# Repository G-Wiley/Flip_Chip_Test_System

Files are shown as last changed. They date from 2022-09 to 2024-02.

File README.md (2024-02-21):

# Flip_Chip_Test_System
This Flip-Chip Tester System enables verification testing and debugging of most M-series and some G-series Flip Chip modules. The system is comprised of a Tester board and a Tester Controller board. An accessory called the IC Test Jig plugs into the UUT socket of the tester which enables functional testing of digital ICs.



<p>This tester PCB is heavily based on a tester designed by Michael Thompson with PCB by Vince Slyngstad. Refer to the StearnsMTvrs files in this folder: 
https://svn.so-much-stuff.com/svn/trunk/Eagle/projects/Stearns%20Tester/
<p>The original Flip-Chip Tester was designed by Warren Stearns.  A more detailed and complete history of the tester evolution is here: 
<br>https://so-much-stuff.com/pdp8/repair/fc-tester.php
<p>This Flip Chip Tester PCB is an updated version of the StearnsMTvrs PCB. The changes to this board include:
<ul>
<li>Increased ground connections between the Tester Controller header and the GPIO Expander chips, and between the GPIO Expander chips and the UUT connector. This was accomplished by using smaller vias and re-routing traces that divided pieces of the ground plane. There are also many more vias that connect between layers and ground fill areas that connect across ground plane sections that are separated by signal traces. </li>
<li>A separate chip select signal is connected to each GPIO Expander.</li>
<li>Updated the pinout of the Tester Controller header to connect the separate SPI chip selects and VCC between the Tester and the Tester Controller circuit card.</li>
</ul>
<p>The Tester Controller circuit card has an ESP32 CPU to control the tester and microSD adapter card for storing test vector files. A possible future update is to combine the Tester and Tester Controller onto a single circuit board. 
<p>The original Stearns Tester software has been ported so it can be built in the Arduino development environment. Some software modifications were necessary due to use of the integrated SPI controller in the ESP32 to drive the SPI link to the GPIO Expanders and microSD adapter. Some changes were necessary to run this as an Arduino application.

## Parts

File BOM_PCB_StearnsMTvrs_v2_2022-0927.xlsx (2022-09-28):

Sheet: Tester Circuit Card
ID | Quantity | Name | MPN | Designator | Footprint | Digikey part number | Source | Link
1 | 4 | 2x18 header | Amazon Break-Away 0.1 Inch 2 x 20-pin Strip Male Header | AX1, AX2, BX1, BX2 (cut to 2x18) | 2X18 | - | Amazon | https://www.amazon.com/dp/B083DYVWDN
 | 72 |  |  | jumpers for 36-pin headers |  | - | Amazon | https://www.amazon.com/dp/B07FKKHHM7
3 | 5 | MCP23S17SP | MCP23S17-E/SP | IC1, IC2, IC3, IC4, IC5 | DIL28-3 | MCP23S17-E/SP-ND | Digikey | https://www.digikey.com/en/products/detail/microchip-technology/MCP23S17-E-SP/894276
 |  |  |  |  |  |  | Mouser | https://www.mouser.com/ProductDetail/Microchip-Technology-Atmel/MCP23S17-E-SP?qs=usxtMOJb1RyzobAZrBjFZA%3D%3D
 |  |  |  |  |  |  | AliExpress | https://www.aliexpress.com/item/3256804178404243.html
 |  |  | ICM-328-1-GT-HT | Sockets for IC1 - IC5 |  | 2057-ICM-328-1-GT-HT-ND | Digikey | https://www.digikey.com/en/products/detail/adam-tech/ICM-328-1-GT-HT/9832998
8 | 19 | 1X01 | single 0.025" header pin with plastic base can cut from: Amazon Break-Away 0.1 Inch 2 x 20-pin Strip Male Header | PROBE1, PROBE2, PROBE3, PROBE4, GNDPROBE, LOADL3, LOADL1, LOADHI3, LOADHI1, GNDL3, GNDL1, GNDL2, GNDL0, LED0, LED1, LED2, LED3, GND, VPP | 1X01 | - | -
9 | 2 | Red LED | Jameco 200 piece LED Grab Bag | RED1, RED2 | LED5MM | - | Jameco | https://www.jameco.com/z/GB110-JAMECO-200-Piece-LED-Grab-Bag-T1-3-4-5mm-T1-3mm-Assorted-Colors-and-Shapes_18041.html
18 | 2 | Yellow LED | Jameco 200 piece LED Grab Bag | UUT_PWR, YELLOW | LED5MM | - | Jameco | https://www.jameco.com/z/GB110-JAMECO-200-Piece-LED-Grab-Bag-T1-3-4-5mm-T1-3mm-Assorted-Colors-and-Shapes_18041.html
20 | 2 | Green LED | Jameco 200 piece LED Grab Bag | PWR, GREEN | LED5MM | - | Jameco | https://www.jameco.com/z/GB110-JAMECO-200-Piece-LED-Grab-Bag-T1-3-4-5mm-T1-3mm-Assorted-Colors-and-Shapes_18041.html
10 | 5 | 300 ohm | Substituted 390Ω | R2[note 2], R3[note 2], R4[note 2], R5[note 2], R14[note 2] | 0207/10 |  | Digikey | https://www.digikey.com/en/products/detail/stackpole-electronics-inc/CF18JT390R/1741695 | 390Ω
11 | 2 | 180 ohm | DNI | R6, R7 | 0207/10 | - | - | -
19 | 2 | 1K ohm | Substituted 390Ω for R12, DNI R13 | R12[note 2], R13[note 1] | 0207/10 |  | Digikey | https://www.digikey.com/en/products/detail/stackpole-electronics-inc/CF18JT390R/1741695 | 390Ω
12 | 2 | 560 ohm | DNI | R8[note 1], R9[note 1] | 0207/10 | - | - | -
13 | 1 | 2K ohm | DNI | R10[note 1] | 0207/10 | - | - | -
14 | 1 | 5.6K ohm | DNI | R11[note 1] | 0207/10 | - | - | -
7 | 1 | 100K ohm | 100K | R1 | 0207/10 |  | Digikey | https://www.digikey.com/en/products/detail/stackpole-electronics-inc/CF18JT100K/1741564
15 | 1 | MA13-2 | Amazon Break-Away 0.1 Inch 2 x 20-pin Strip Male Header | PC1 (cut to 2x10) | MA13-2 | - | Amazon | https://www.amazon.com/dp/B083DYVWDN
16 | 2 | 1N4001 | 1N4001 | D1, D2 | DO41-10 | 1N4001DICT-ND - Cut Tape (CT) | Digikey | https://www.digikey.com/en/products/detail/diodes-incorporated/1N4001-T/601
17 | 1 | 710X | 7101SYCBE | UUT | 7109MD9V3 | CKN1003-ND | Digikey | https://www.digikey.com/en/products/detail/c-k/7101SYCBE/13637
21 | 1 | 47uF | any value from 47uF to 100uF, 10V or greater, that fits | C1 | E5-8,5 |  | Digikey
22 | 6 | .22uF | C330C224M1R5TA | C2, C3, C4, C5, C6, C7 | C050-025X075 | 399-13966-ND | Digikey | https://www.digikey.com/en/products/detail/kemet/C330C224M1R5TA/6562377
23 | 1 | 1X6MTA | 1-1123723-6 | POWER, header | 1X6MTA | A106606-ND | Digikey | https://www.digikey.com/en/products/detail/te-connectivity-amp-connectors/1-1123723-6/686929
 | 1 |  |  | Power, mating connector |  | 5-1123722-6-SI-ND | Digikey | https://www.digikey.com/en/products/detail/te-connectivity-amp-connectors/5-1123722-6/4730307
 | 3 |  | 1123721-2 | pins for mating connector |  | A100446CT-ND | Digikey | https://www.digikey.com/en/products/detail/te-connectivity-amp-connectors/1123721-2/686921
24 | 1 | dual 2x18 | Omnibus-compatible connector | EDAC | EDAC346-36-2 | - | AliExpress | https://www.aliexpress.com/item/2255801094078491.html
 |  |  |  | Note 1: I chose not to install R8, R9, R10, R13 yet. Didn't use these Loads for any of the PDP-8/L Flip Chip tests.
 |  |  |  | Note 2: I substituted 390 ohms at R2, R3, R4, R5, R12, R14. You may want to adjust the value so the LED brightness is to your liking.

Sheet: Tester Controller ESP32
ID | Quantity | Name | MPN | Designator | Footprint | Digikey part number | Source | Link
1 | 1 | DOIT ESP32 DEVKIT v1 | DOIT ESP32 DEVKIT v1 | U1 |  | - | Amazon | https://www.amazon.com/ESP32-WROOM-32-Development-ESP-32S-Bluetooth-Arduino/dp/B084KWNMM4
2 | 2 | 1x15 female header strip | Amazon 40 Pin 2.54mm Single Row Straight Female Header | cut two strips of 1x15 | 1x15 | - | Amazon | https://www.amazon.com/dp/B07CGGSDWF
3 | 1 | 2x10 header | Amazon Break-Away 0.1 Inch 2 x 20-pin Strip Male Header | J1 (cut to 2x10) | 2x10 | - | Amazon | https://www.amazon.com/dp/B083DYVWDN
4 | 2 | 220 nF | C330C224M1R5TA | C1, C2 |  | 399-13966-ND | Digikey | https://www.digikey.com/en/products/detail/kemet/C330C224M1R5TA/6562377
5 | 1 | BAT86 | BAT86 | D1 |  | 1655-SB140CT-ND | Digikey | https://www.digikey.com/en/products/detail/smc-diode-solutions/SB140/6022604
6 | 1 | MicroSD module | Micro SD TF Card Adater Reader Module | U2 |  | - | Amazon | https://www.amazon.com/gp/product/B07BJ2P6X6/
7 | 1 | 1x6 female header strip | Amazon 40 Pin 2.54mm Single Row Straight Female Header | cut one strip of 1x6 |  | - | Amazon | https://www.amazon.com/dp/B07CGGSDWF
8 | 1 | SN74AHC125N | SN74AHC125NG4 | U3 |  | 296-4531-5-ND | Digikey | https://www.digikey.com/en/products/detail/texas-instruments/SN74AHC125N/375724
9 | 1 | 2x1 header | Amazon Break-Away 0.1 Inch 2 x 20-pin Strip Male Header | J2 (cut to 2x1) | 2x1 | - | Amazon | https://www.amazon.com/dp/B083DYVWDN
10 | 1 | PCB | - | - | - | - | JLCPCB | https://jlcpcb.com/
11 | 2 | DNI | DNI | R1, R2 |  | - | - | -

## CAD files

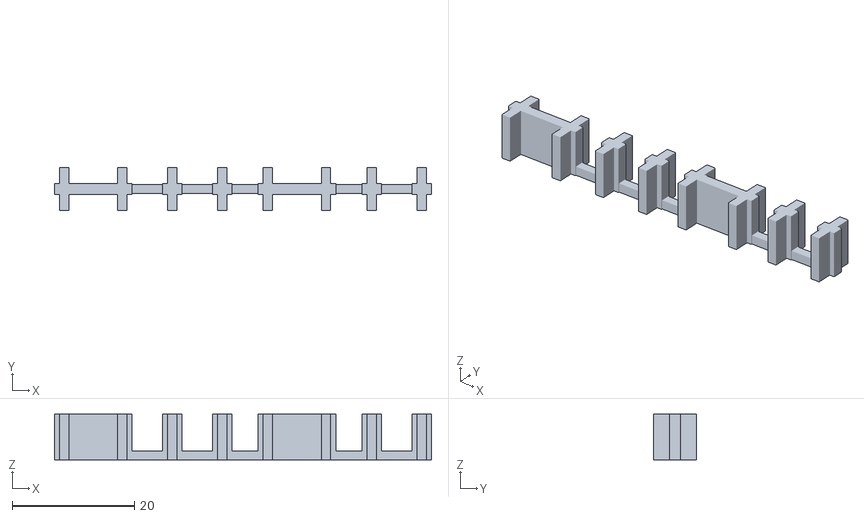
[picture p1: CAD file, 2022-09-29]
Flip_Chip_Tester_shims_v00.stl
61.8 x 7.01 x 7.51

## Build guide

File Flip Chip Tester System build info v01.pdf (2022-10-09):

# Flip Chip Tester System Build Information

## - The following pages describe how to build and set-up the Flip Chip Tester System. • The Flip Chip Tester System is

## comprised of a Tester Controller circuit card and a Tester circuit card. Both circuit cards are connected via a 20-pin flat cable. The Tester Controller has a microSD adapter so test programs can

be retrieved from a microSD card.

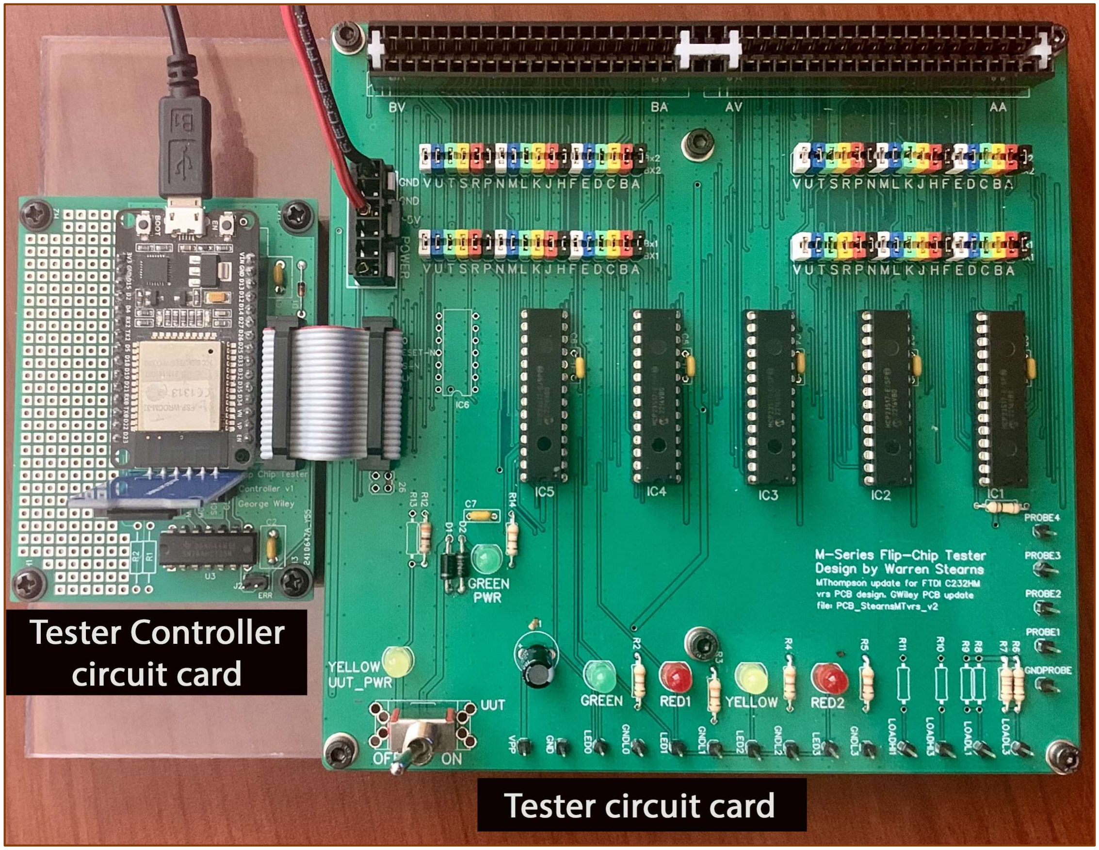
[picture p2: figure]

Flip Chip Tester System build information | 1

The Flip-Chip Tester System is a tool to perform verification testing and debugging of most M-series and some G-series Flip Chip modules. The system is comprised of a Tester board and a Tester Controller board connected together via a 20-pin flat cable. A photo of the entire system is on the previous page. The Tester Controller has a microSD adapter so test programs can be retrieved locally from a microSD card.
An accessory called the “IC Test Jig” plugs into the UUT socket of the tester which enables functional testing of digital ICs.
This Tester board is based on a tester designed by Michael Thompson with PCB by Vince Slyngstad. Refer to the StearnsMTvrs files in this folder: https://svn.so-much-stuff.com/svn/trunk/Eagle/projects/Stearns%20Tester/
The original Flip-Chip Tester was designed by Warren Stearns. There was a version of this original tester that connected to a PC through a parallel printer port, and I believe another version controlled by an MC6809 microprocessor. A more detailed and complete history of the tester evolution is here: https://so-much-stuff.com/pdp8/repair/fc-tester.php
It is important to mention that a significant library of test vector files has already been created by the original developers of the tester to test “M” and “G” series Flip Chip modules. These are mainly the single and double width modules used in the PDP-8/L and PDP-8/I. This library of existing tests is a tremendous benefit to the PDP-8 enthusiast community. https://svn.so-much-stuff.com/svn/trunk/pdp8/warren/16bit/tests/
There are also some PDP-8/L module test files in the repository:

“Flip_Chip_test_procedures_and_vectors” https://github.com/G-Wiley/Flip_Chip_test_procedures_and_vectors

## Background

Flip Chip Tester System build information | 2

The Tester circuit card is comprised of a set of five MCP23S17 16-bit GPIO Expander chips and a double-wide Flip Chip connector. The configurability of the GPIO Expander chips makes it possible for each Flip Chip module pin, the Unit Under Test (UUT) to be configured individually as an output or input.
Each MCP23S17 16-bit GPIO Expander has an SPI port which is connected to the tester controller CPU. The SPI bus MISO and MOSI signals of all 5 GPIO expander chips are tied to common MISO and MOSI signals and each GPIO expander has its own chip select signal and device address.
The tester controller consists of an ESP32 module and a microSD card adapter module. The microSD card adapter is on the same SPI bus as the GPIO Expanders on the Tester circuit card, but the microSD card adapter has a unique chip select signal so the CPU can address only one device at a time. A prototype version of the Tester Controller is shown below.
The MISO signal from the microSD adapter is connected through an SN74AHC125 tri-state buffer enabled by the microSD chip select so that the global SPI MISO signal is driven only when the microSD is accessed. This makes it possible for the microSD card adapter and MCP23S17 16-bit GPIO Expanders to share the same SPI.
The original Stearns tester software has been ported to run on the ESP32 and compiled in the Arduino development environment. Modifications have been made to add the ability to access the microSD adapter and to access the GPIO Expanders one at a time over the common MISO and MOSI signals. The printer port I/O handlers have been removed and replaced with handlers to communicate with the MCP23S17 GPIO Expanders over the SPI.

## 2 x 43 pin connector modifications

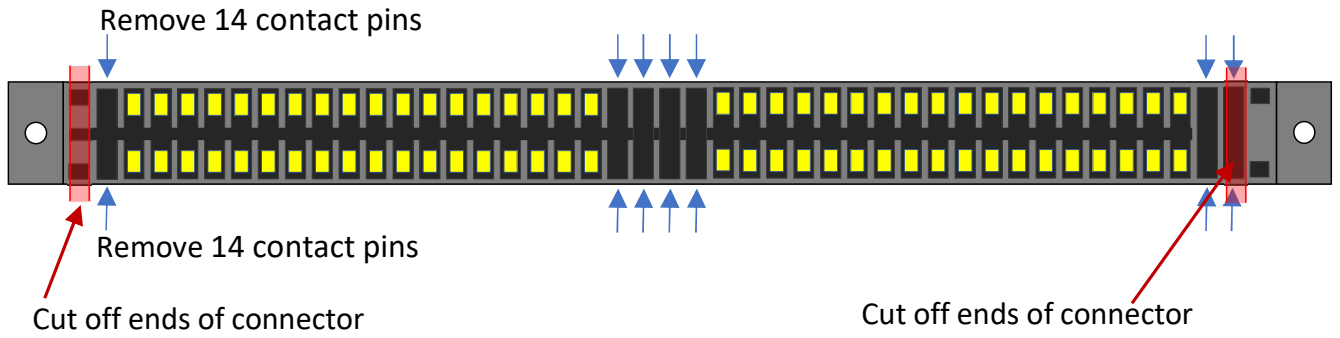
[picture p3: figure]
Remove 14 contact pins; Cut off ends of connector

Note: It is possible to avoid cutting the ends of the connector. However, the extra width will interfere with two of the standoff mounting holes on the Tester PCB.

## Instructions to modify the edge connector #1

Flip Chip Tester System build information | 3

The connector that holds the UUT is purchased as a single 2 x 43 pin connector. It needs to be modified so it can accept either a single or dual Flip Chip module and have that module be properly aligned with the connector contact pins. Also, the connector, as purchased, is too wide to be installed in the Tester PCB and would interfere with two of the mounting screws on the Tester circuit card.
The following instructions describe how to remove unused contact pins, cut the connector to the proper width, and insert shims into the unused contact pin locations so the UUT will be properly aligned when it is inserted into the socket.

## Remove the extra connector contact pins

Remove the extra connector contact pins before cutting. The contact pins to be removed are indicated by the blue arrows on the previous page. Removal of pins is necessary so the saw blade doesn’t bind on the metal contact pins, and so the shims will fit in the empty contact positions.

An easy way to remove the pins is to place the connector slot-side down, pin-side up, on a flat surface that has an opening that allows the pins to be easily pushed through. The photo below shows an example of needle nose pliers gripping a contact pin which is pressed downward.

The example below shows two sides of a desk supporting the connector. A simple alternative would be to drill a large hole in a block of wood to support the connector while pushing the contact pin downward but to allow the removed pin to slip through the opening.

## Instructions to modify the edge connector #2

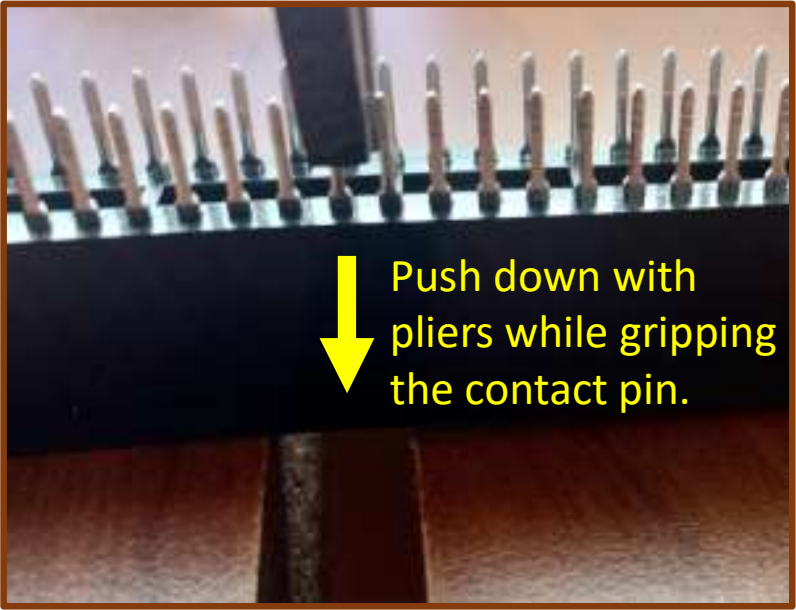
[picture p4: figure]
Push down with pliers while gripping the contact pin.

Flip Chip Tester System build information | 4

## Cutting the edge connectors

I used a small 7 ¼ inch power miter saw with a 140-tooth blade. Make the cuts at the locations indicated by the red bands on the first page.

The photo below shows a guide taped to the saw that is used to help align the connector during the cutting process. Notice the icon in the lower left warning to not put your hand there, so a clamp is necessary to secure the connector while cutting. Small marks from the connector pins are visible on the paper guide. I didn't have the marks perfectly aligned when I attached the paper guide and adjusted the position of the connector early in the cutting process. The connector pins made the small dots to the right of the larger marks. The connector was cut lying flat with the open slot toward the front and the pins pressed against the guide. When cutting the ends, take care to leave the full thickness of the connector pin separation wall at the outside of the connector so the single-width shims on the outside spaces will fit tightly.

## Instructions to modify the edge connector #3

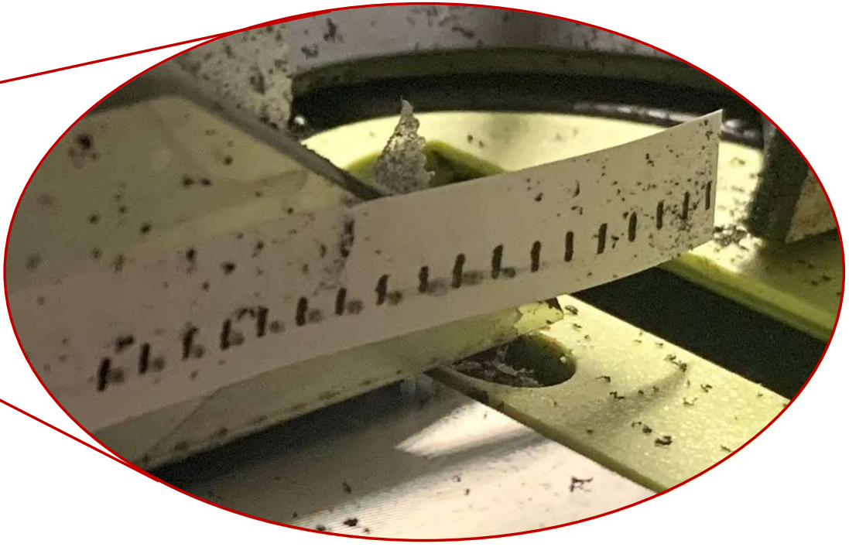
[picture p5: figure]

Flip Chip Tester System build information | 5

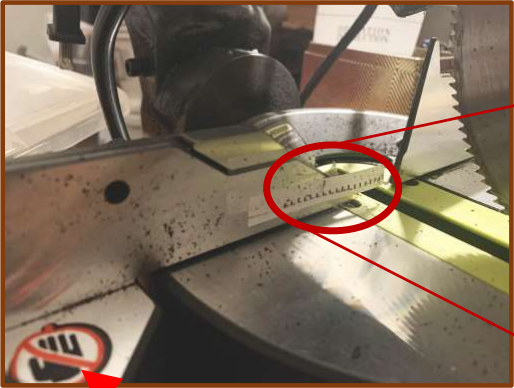
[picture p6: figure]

## Connector Shims #1

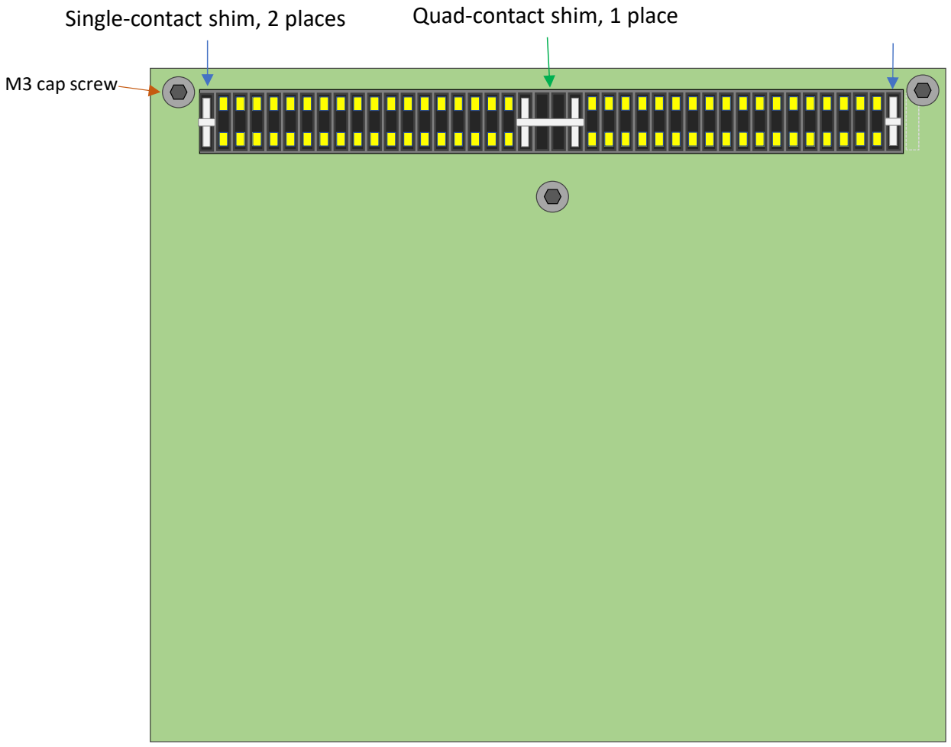
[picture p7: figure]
Single-contact shim, 2 places; Quad-contact shim, 1 place; M3 cap screw

Flip Chip Tester System build information

The connector shims are 3D printed in a small rack that contains twice the number of shims required for a Flip Chip Tester. It’s nice to have extras in case these small pieces are lost or damaged. There are 2 quad-contact shims and 4 single-contact shims. An entire set of shims are printed together because it is easier to handle a single 3D print job and it reduces the printing cost. The shims in the image below were printed at JLCPCB in LEDO 6060 Resin. The file to be printed is “Flip_Chip_Tester_shims_v00.stl”, an STL format file in millimeter units. (At JLCPCB, simply upload the file, choose “LEDO 6060 Resin”, and order the part.)
A 1.5 mm disposable rib connects the entire set of shims. They can be cut apart easily using a set of diagonal cutters that is flat on one side. When separating a single shim, place the flat side of the diagonal cutter next to the part you are removing from the rib.
The two single-contact shims might fit rather loosely in the connector if the outside spacer walls were cut too thin. If so, they should be glued so they remain in place. A tiny sub-drop of epoxy should hold the shim in place. Be very careful not to get any glue on the connector contacts.

## Connector Shims #2

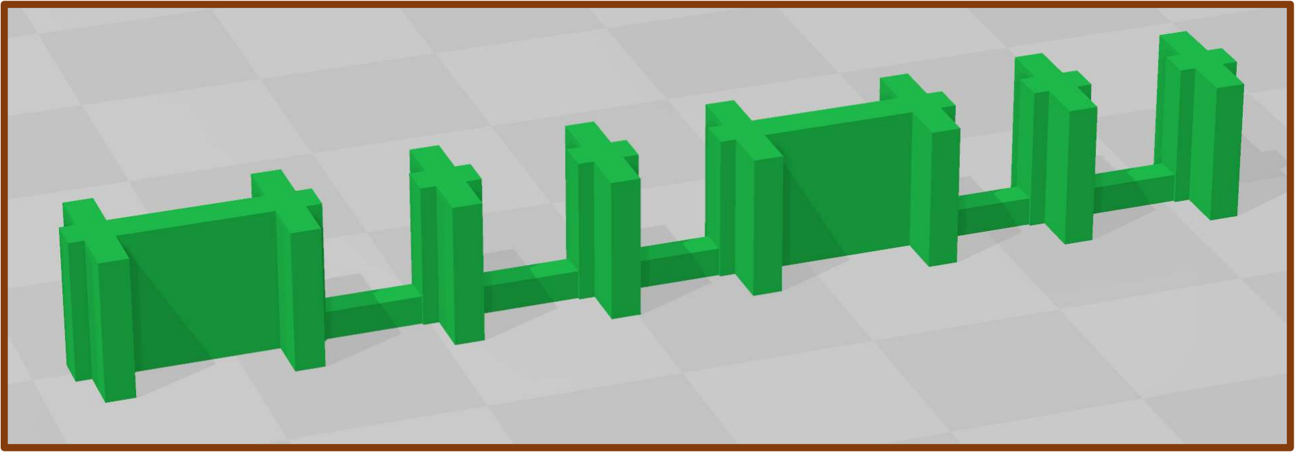
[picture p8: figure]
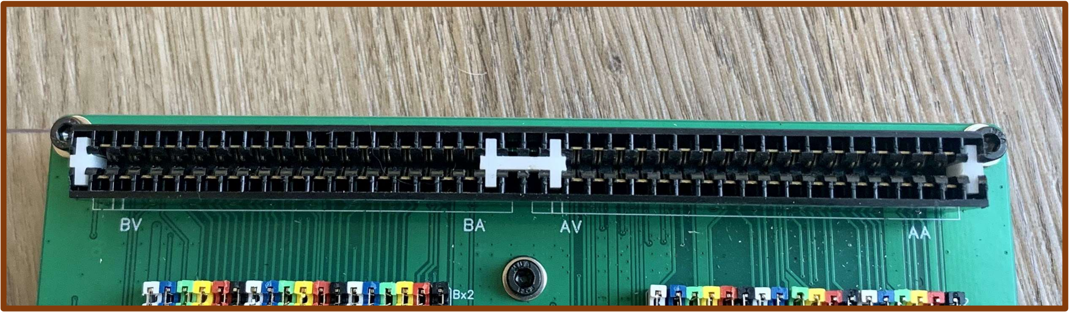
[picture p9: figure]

Flip Chip Tester System build information | 7

PCBs:
The Tester and Tester Controller were designed to be fabricated with the most basic PCB process. Both boards can be fabricated from standard 1.6 mm thick FR4 material or a different thickness can be used without any adverse effects. The Lead Free HASL-RoHS process is recommended. There are two sets of Gerber files: • “Gerber_PCB_StearnsMTvrs_v2.zip” for the Tester board. • “Gerber_PCB_FlipChip Tester Controller ESP32 v1.zip” for the Tester Controller board.

For example: At JLCPCB, simply upload each zip file, choose “LeadFree HASL-RoHS” process, and proceed to checkout. You may want to order the boards separately to avoid confusion.

Note: • Tester board “Gerber_PCB_StearnsMTvrs_v2.zip” requires some modifications but is available now.

The rework instructions are in: “Rework Instructions for the Module Tester PCB v2.pdf”
- Tester board “Gerber_PCB_StearnsMTvrs_v3.zip” has the bugs fixed but has not yet been released (as of 8-Oct-2022).

Shims:
The shims were designed to be fabricated using a low-cost 3D-printing process. As mentioned previously, there is a single STL file for printing two sets of shims for the tester: • “Flip_Chip_Tester_shims_v00.stl”

For example: At JLCPCB, simply navigate to the 3D printing area, upload the STL file, choose “LEDO 6060 Resin”, and order the part.

## Ordering the PCBs and Shims

Flip Chip Tester System build information | 8

There’s not much unusual here. The components are installed as indicated by the BOM spreadsheet: “BOM_PCB_StearnsMTvrs_v2_2022-0927.xls” The Tester BOM is the “Tester Circuit Card” worksheet.
Some components are not installed as noted in the BOM. R6 through R11 & R13 are DNI.
The PCB is designed with pads for a 26-pin header at location PC1, but a 20-pin header should be installed in that location instead. The 20-pin header should be installed at pins 1 through 20 with nothing installed in pins 21 through 26.

Install 72 jumper plugs onto the four 36-pin headers. It’s convenient to use multiple-colored jumpers so it’s easier to see which pin label on the board silkscreen aligns with the metallic contact at the top of each jumper plug. This is useful when probing signals at the top of the jumper plugs while running scope loop tests. Board edge connector signals can more easily be probed at the tops of the jumper plugs compared to counting gold fingers on the front and back of the UUT. Also, a scope probe with the witch’s hat attachment can be clipped to the tops of the jumper plugs.

## Mounting Components on the PCBs

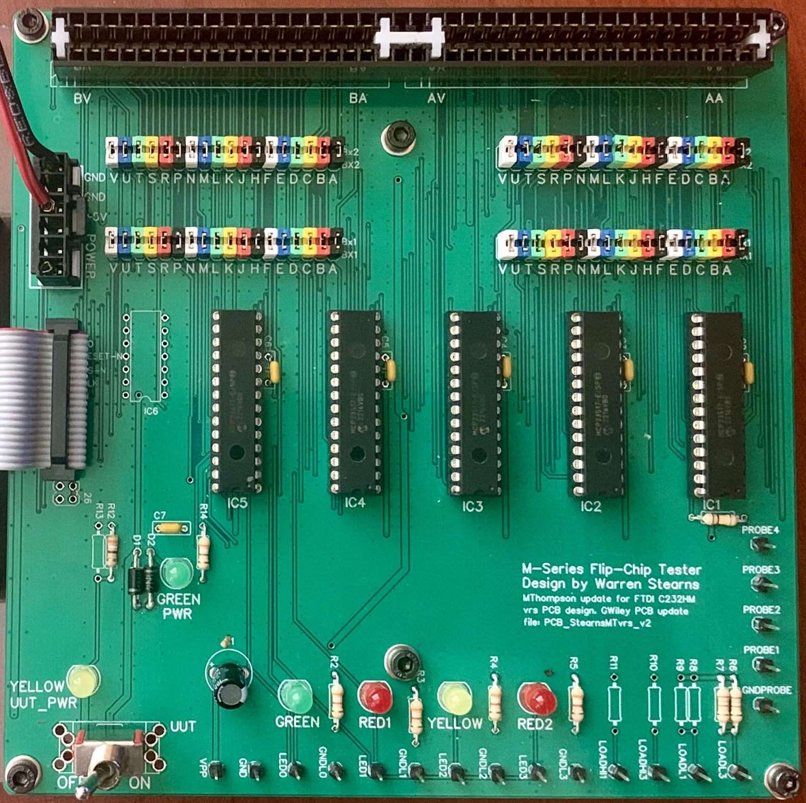
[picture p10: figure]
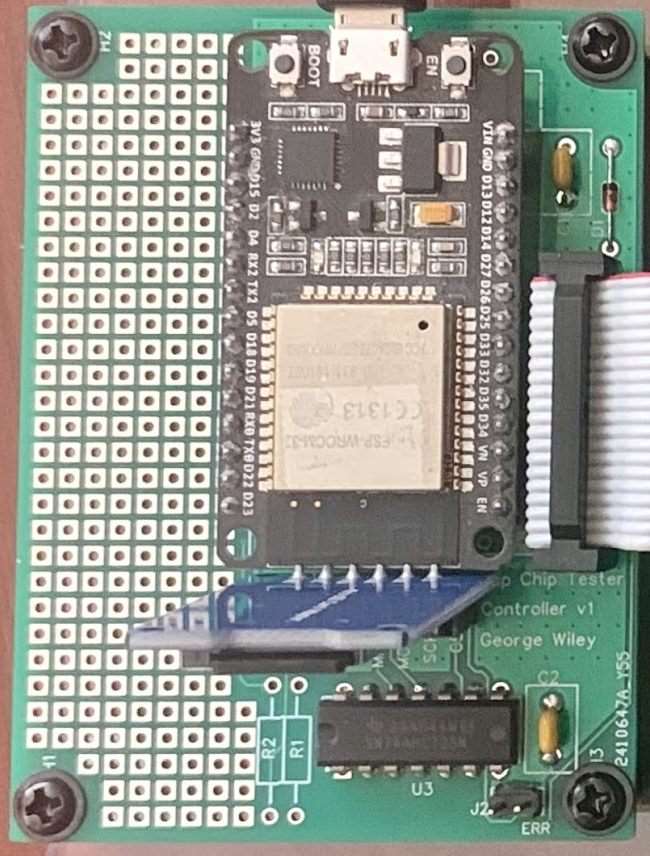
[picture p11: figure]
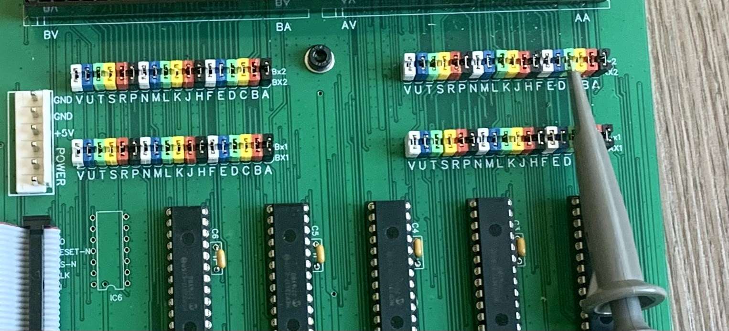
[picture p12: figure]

Flip Chip Tester System build information | 9

## Tester PCB

The components are installed as indicated on the BOM spreadsheet: “BOM_PCB_StearnsMTvrs_v2_2022-0927.xls” The Tester Controller is the “Tester Controller ESP32” worksheet.
Some components are not installed as noted in the BOM. R1 & R2 are DNI.

## Tester Controller PCB

The drawing to the right shows the locations of the mounting holes for the Tester Controller and Tester circuit boards. The hole size should be about 1/8” (3.2 mm to 3.4 mm) for proper clearance for an M3 screw. The screw locations shown will result in perfect alignment of the 20-pin headers on both boards.

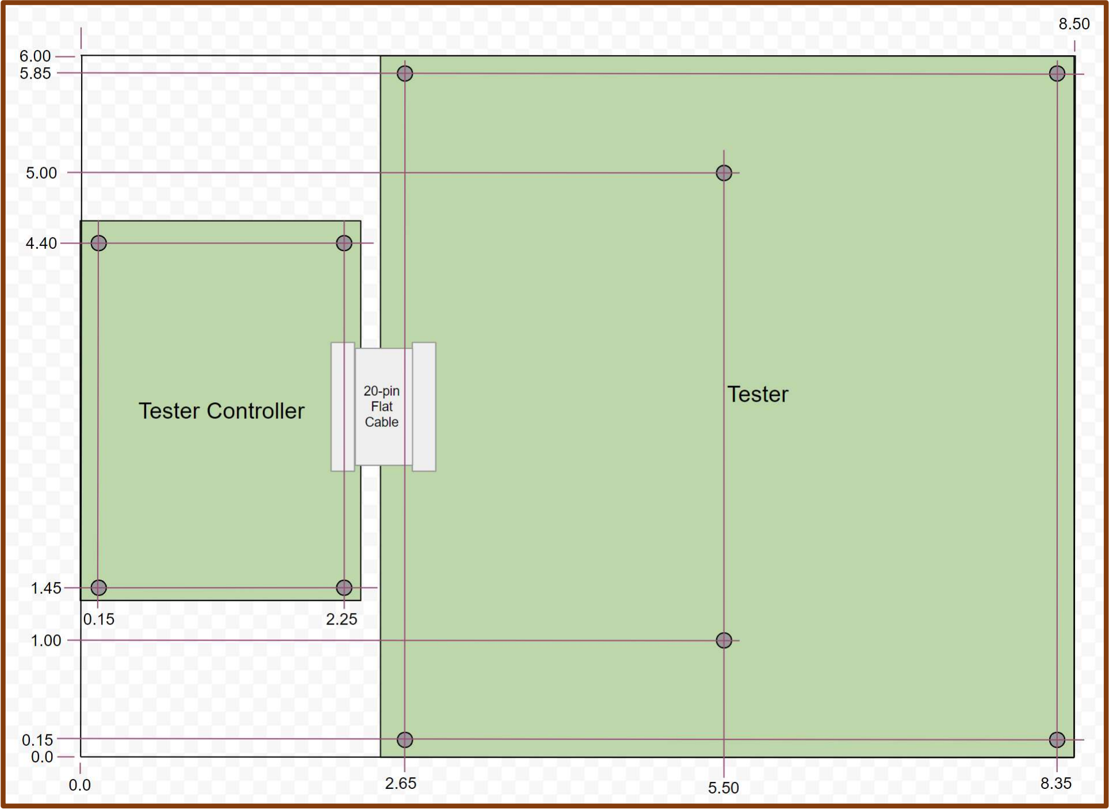
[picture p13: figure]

Flip Chip Tester System build information | 10

## Tester and Tester Controller Mounting on ¼” Acrylic Base #1

Use M3 hardware to mount the Tester and Tester Controller to an acrylic base. M3 cap screws have a small diameter head so they fit well in the mounting holes at the corners of the Tester board. A screw with a large diameter head can overlap the edges of the board in the corner hole locations. Tall adhesive rubber feet prevent the screws on the bottom of the acrylic sheet from scratching the desktop. Take care to ensure the 20-pin headers on the Tester Controller and Tester board are perfectly aligned so the flat cable can connect straight across between the two boards without any bending of folding. This will also allow the flat cable to be as short as possible.

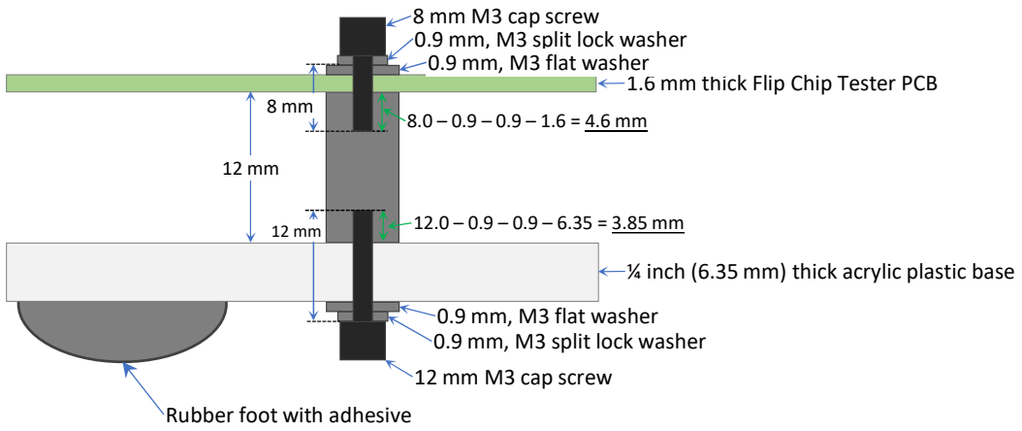
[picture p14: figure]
0.9 mm, M3 split lock washer; 0.9 mm, M3 flat washer; 8 mm M3 cap screw; 12 mm M3 cap screw; 1.6 mm thick Flip Chip Tester PCB; Rubber foot with adhesive

## Mounting without Acrylic Base

Although the thick acrylic base provides the best support for both insertion and removal of boards, it is also possible to use the Tester with the nylon standoffs as supporting feet. Mounting to an acrylic base provides better support when removing Flip Chip modules. Also, mounting to a base provides better support for the two boards which are connected via a 20-pin flat cable.

¼ inch (6.35 mm) thick acrylic plastic base

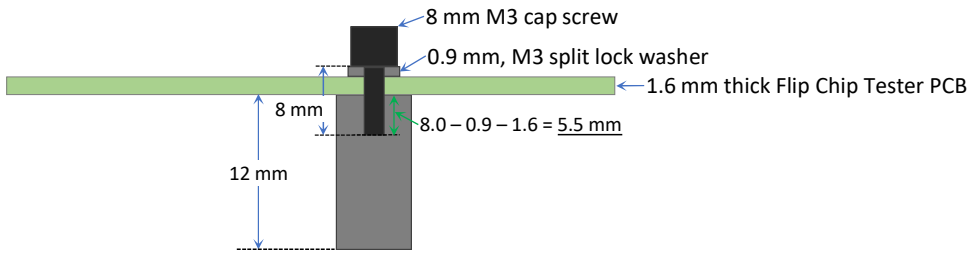
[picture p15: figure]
0.9 mm, M3 split lock washer; 8 mm M3 cap screw; 1.6 mm thick Flip Chip Tester PCB

Flip Chip Tester System build information | 11

## Tester and Tester Controller Mounting on ¼” Acrylic Base #2

Mount the two boards to an acrylic base using 12 mm nylon standoffs and M3 hardware as previously described. Connect a 20-pin flat cable between the boards. Connect a micro-USB cable to the connector on the ESP32 module and connect the other end to the computer where the Arduino development environment is installed.
Copy the test files with “.TST” extension to a microSD card.
Download the test files from: • https://svn.so-much-stuff.com/svn/trunk/pdp8/warren/16bit/tests/
- https://github.com/G-Wiley/Flip_Chip_test_procedures_and_vectors
Save the test files to the microSD card. You can save them to the root level because no other files need to be saved on the microSD card.

## Setting up the Tester System for use

Flip Chip Tester System build information | 12

## Final Assembly

## The Arduino Development Environment for the Tester

Flip Chip Tester System build information | 13

## Setting up the Arduino environment

The following are helpful tutorials to get your Arduino dev tools set up properly for the ESP32: • https://randomnerdtutorials.com/getting-started-with-esp32/

- https://randomnerdtutorials.com/installing-the-esp32-board-in-arduino-ide-windows-instructions/
- ESP32: Guide for MicroSD Card Module using Arduino IDE: https://RandomNerdTutorials.com/esp32-microsd-card-arduino/
- The Arduino SPI library: https://docs.arduino.cc/learn/communication/spi
I highly recommend getting the DOIT ESP32 DEVKIT V1 module so it matches the tutorial. This is the module specified in the Tester Controller parts list.

Download the Tester Controller Arduino code from github to the host PC. The “.ino” files need to be in a folder of the same name, but the folder name is without the “.ino” file extension. This is a requirement for the Arduino tools to work properly. For example: copy the file ESP32_blink_v00.ino to a folder named ESP32_blink_v00
The following two files are useful to test that the Arduino environment is set up properly and to test the hardware: • ESP32_blink_v00.ino – a very simple program that blinks the LED on the ESP32

module. This will also work with the ESP32 not inserted in the Tester Controller board; just the ESP32 board sitting on a table and connected to the USB cable will work. This program is good to verify that the Arduino development environment is set up properly. It does not require the SD library or SPI. • ESP32_blinkSPI_v03.ino – blinks the LEDs on the Tester board out of phase with

the ESP32 module blue LED blinking. It does require SPI to communicate with the MCP23S17 chips but does not use the microSD file system.
The Flip Chip Tester software is in one file: • DOIT flipchip_tester_ESP32_v01.ino – the Flip Chip Tester operating software.

This requires use of SPI and the microSD file system. At the time you are reading this, the current version might be later than v02, so modify the instructions accordingly.

The following assumes that the reader has some familiarity with the Arduino development environment. If needed, refer to the tutorial links mentioned previously.

### 1. Set up the Arduino environment for the DOIT ESP32 DEVKIT V1 module:

https://randomnerdtutorials.com/installing-the-esp32-board-in-arduino-ide-windows-instructions/

### 2. It might be also necessary to install the SD library:

https://github.com/espressif/arduino-esp32/tree/master/libraries/SD

### 3. Download the code from github: flipchip_tester_esp32_v01.ino and save it on

your computer in a folder with the same name, flipchip_tester_esp32_v01
4. In Arduino, open flipchip_tester_esp32_v01.ino.
Set the serial port: Tools → Port and select the proper COM port.
Set the board type: Tools → Board and select DOIT ESP32 DEVKIT V1
Compile and upload to the ESP32: Sketch → Upload

### 5. If there are problems, the following can be used to isolate faults:

a. A simple program to blink the LEDs on the Tester circuit card and the on-board ESP32 blue LED out-of-phase with each other is in github: ESP32_blinkSPI_v03.ino. b. The most simple blinker… If there are more basic problems then try this simple program to

blink just the on-board LED on the ESP32 module. It’s in github: ESP32_blink_v00.ino This simple blinker needs only the DOIT ESP32 DEVKIT V1 module connected to the host computer via USB. It is powered through USB. No external power is required. The ESP32 module does not need to be attached to the Tester Controller circuit card.
c. If there are problems with the microSD, either with the software build or functionality, then try to run the simple Rui Santos example code at the bottom of this page: https://randomnerdtutorials.com/esp32-microsd-card-arduino/
The 20-pin flat cable to the Tester board can be removed if you like while running this example code so that only the microSD adapter is connected to the SPI signals. The serial baud rate for this example code is 115200. Tools → Serial Monitor is helpful.

### 6. The Tester Controller is configured for console I/O through the USB serial port

running at 921,600 baud. A simple terminal emulator such as Putty is useful. If a different baud rate is preferred then search for this line of code: Serial.begin(921600); and change the baud rate parameter.

### 7. It’s helpful to power the tester with a lab power supply adjusted to output 5.0

volts so the current consumption can be observed while running tests.

## High-Level Instructions

After loading flipchip_tester_ESP32_v01.ino into the ESP32 module using the Arduino dev tools, run a terminal emulator program such as Putty. The Flip Chip Tester software initializes the serial port to run at 921,600, so set the baud rate in Putty to 921,600 bps. If necessary, the baud rate can be modified by changing the value in the Serial.begin(921600) function call. The Tester splash screen will probably display immediately after starting Putty. If not, then press the “EN” button on the ESP32 module (next to the USB connector), not the “BOOT” button. The “EN” button will reset the ESP32.

Most of the original Stearns Tester commands are still supported. Some functions are not available if they no longer make sense, such as: the “Exit” command from the main menu and diagnostic test commands LPT functions (that test the PC parallel port) and SPI functions.

Each Flip Chip module has one or more associated test files with file extension “TST”. Save the TST files on a microSD card and then plug that microSD into the socket on the Tester Controller. It’s probably easier to save the TST files to the root level of the microSD card. The original Flip Chip TST files are available here: https://svn.so-much-stuff.com/svn/trunk/pdp8/warren/16bit/tests/
Some additional scope loop tests for PDP-8/L modules are here: https://github.com/G-Wiley/Flip_Chip_test_procedures_and_vectors
Test Data Sheets that describe how to run each test are available in this same github repository. These Test Data Sheets are needed to properly run the scope loop tests.

If it’s necessary to add TST files to the microSD card then the Tester Controller must be reset after the microSD is re-inserted into the socket on the tester.

Simple tester use instructions:
1. From the main menu, “1” (read test file), then type in the test file name, such as M113.TST followed by the “Enter” key. Filenames are not case-sensitive.
2. With the UUT power switch on the Tester board in the “OFF” position (handle to the left), insert the module you want to test into the UUT socket. Single modules go in the right side and double modules use both sides. The A and B pin labels are indicated on the Tester board silkscreen next to the UUT socket.
3. Turn on the UUT power switch on the Tester board (handle to the right). If the switch remains off then the tester software will complain in the next step.
4. To run the test, “4” (run test).
5. Nine different testing options are now available. The most useful are “O” and “S”. “O” runs a test once and specific errors are displayed. “S” is a scope loop test mode where the test is looped at high speed and only a pass/fail status is displayed for each loop through the test vectors. Some Flip Chip tests can only be run as scope loop tests where the pass-fail criteria is determined by examining a waveform on the scope.

### 6. For scope tests & debugging:

Error Pulse: When using the scope loop test mode (“S” command), the ERR testpoint on the Tester Controller board will produce a narrow positive pulse every cycle where an error occurs. The pulse will appear at the end of the specific vector cycle so look at the logic state of pins just prior to this pulse to observe the conditions that caused the failure in that clock cycle.
Start of Test Pulse: The LED3 testpoint on the Tester PCB produces a positive pulse at the beginning of the cycle of tests. It is useful to use this signal as a scope trigger for scope loop tests. The time of this LED3 pulse can be adjusted using the Tester main menu command “2”, set test delay. The default delay is zero.

## Using the Tester

Flip Chip Tester System build information | 14

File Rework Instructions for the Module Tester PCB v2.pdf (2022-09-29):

Module Tester v2 Rework Instructions | page 1

### Rework Instructions for the Module Tester PCB v2

The following rework is necessary for all PCBs fabricated using Gerber file: Gerber_PCB_StearnsMTvrs_v2_2022-06-29c.zip
The board silkscreen shows: “file: PCB_StearnsMTvrs_v2”
It’s recommended to locate all cuts so they are visible after components are installed, if that is possible. This is so the cuts are visible later if there is an issue.
Cuts on the component side (Layer 1):
1. Cut trace between PC1-10 and PC1-12.
2. Cut trace between PC1-12 and PC1-14.
3. Cut trace between PC1-14 and PC1-16.
4. Cut trace between PC1-16 and PC1-18.
5. Cut trace between PC1-20 and PC1-22.
Cuts on the circuit side (Layer 2):
1. Cut trace leading to PC1-20.
2. Cut trace between IC5-11 and IC4-11, close to C6.
3. Cut trace between IC4-11 and IC3-11, close to C5.
4. Cut trace between IC3-11 and IC2-11, close to C4.
5. Cut trace between IC2-11 and IC1-11, close to C3.
Add jumpers on the circuit side (Layer 2):
1. Jumper from anode of D1 to PC1-20. This is a +5V VCC trace so it can be a thicker jumper.
2. Jumper from IC1-11 to PC1-18 (signal CS-IC1-N).
3. Jumper from IC2-11 to PC1-16 (signal CS-IC2-N).
4. Jumper from IC3-11 to PC1-14 (signal CS-IC3-N).
5. Jumper from IC4-11 to PC1-12 (signal CS-IC4-N).

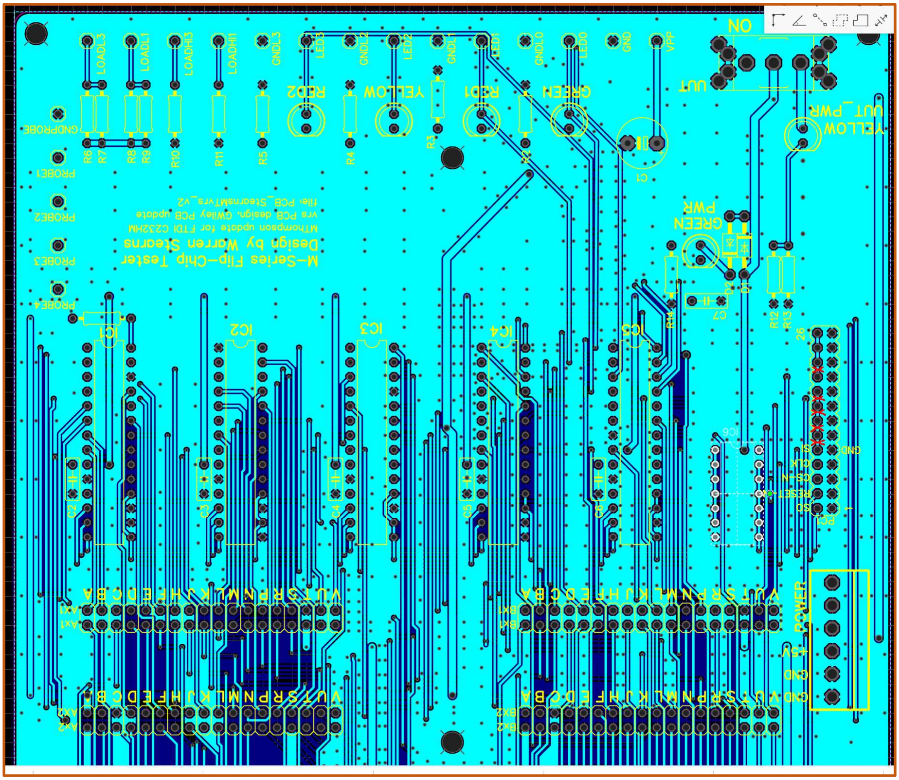
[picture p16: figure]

Module Tester v2 Rework Instructions | page 2

Image showing 5 cuts on the component side (Layer 1)

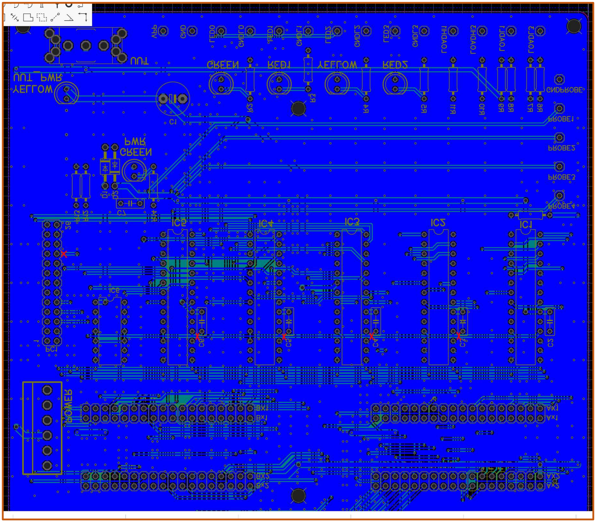
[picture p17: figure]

Module Tester v2 Rework Instructions | page 3

Image showing 5 cuts on the circuit side (Layer 2)

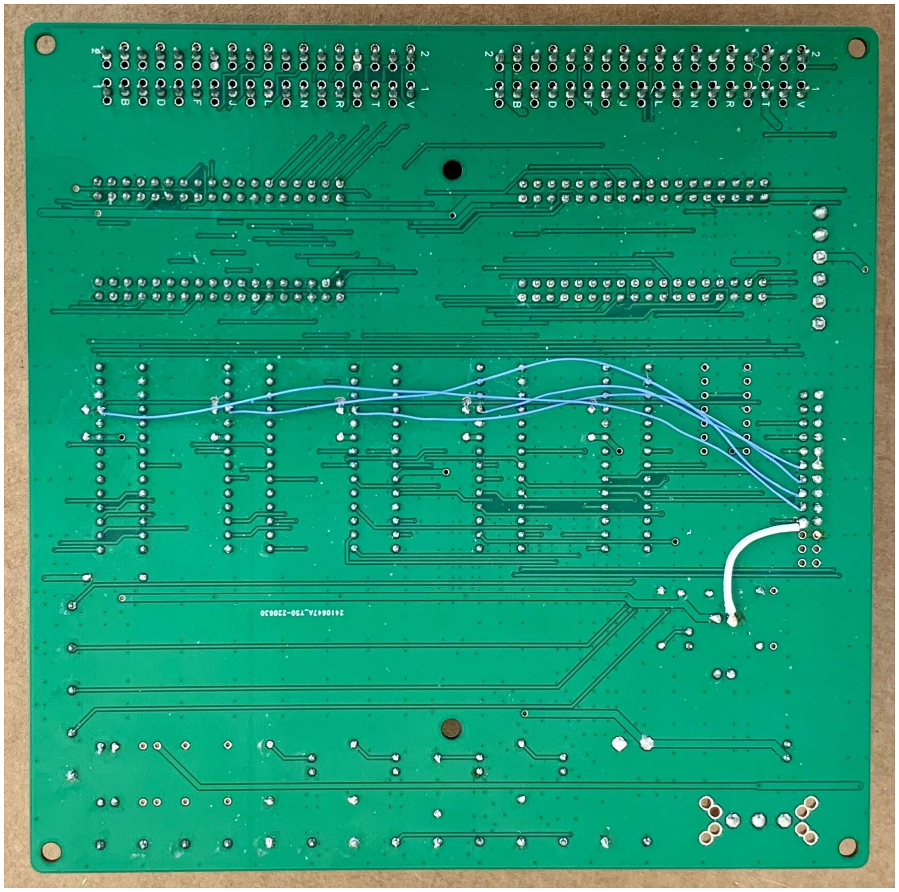
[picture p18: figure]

Module Tester v2 Rework Instructions | page 4

Image showing 5 jumpers on the circuit side (Layer 2)

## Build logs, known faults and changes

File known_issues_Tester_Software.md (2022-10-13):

<b>known issues Flip Chip Tester Software</b>
<p>
<ol>
<li>Sometimes when running one test using the "O" or "F" commands, errors are reported when testing a good board. The scope loop test, "S", doesn't have
this issue. However, after testing multiple times using the "O" command when false errors are flagged, then when running the "S" command
afterward, the "S" command output will indicate test failures. So, running the "O" command seems to pollute the "S" command result. 
The root cause still needs to be found.</li>
<li>The "set test delay", main menu command "2", has not yet been verified on the ESP32 code.</li>
<li>The "output loading test", main menu command "5", has not yet been verified on the ESP32 code.</li>
<li>In the sub-menu under "run test", the following have not yet been verified:
  <ul>
    <li>"G" - "go (run tests)".</li>
    <li>"N" - "run, stop on fail, no print".</li>
    <li>"C" - "turn on comment printout".</li>
    <li>"+" - "increase speed (less delay)".</li>
    <li>"-" - "decrease speed (more delay)(slower)".</li>
  </ul></li>
  <li>Writing to the log file has temporarily been commented out in the print() function.</li>
  <li>Would be useful to add the ability to define a bi-directional signal so a signal can be either 0, 1, or hi-Z. This would be useful to test bi-directional signals and devices like AOI gates with expander inputs.</li>
</ol>
<p>Regarding items that have not yet been verified: these functions probably worked properly in the original Stearns tester code. They need to be re-confirmed on the ESP32 code to verify that nothing has been broken when the code was ported.

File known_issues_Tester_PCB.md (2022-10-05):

<b>known issues Flip Chip Tester PCB</b>
<p>
<ol>
<li>Testpoint pads are too small - the testpoint pads are too small and do not provide a strong base. After moderate use, the solder joints on some of the testpoint pins can come loose. A fix has been identified, the testpoint pads are larger, to be included in v3.</li>
<li>Some cuts and jumps are required. A fix will be included in v3.</li>
<li>There are two current limiting resistors for the UUT power LED. Delete one of them. A fix will be included in v3.</li>
<li>Header PC1 is 26 pins. Need only 20 pins. Use a 20-pin symbol instead.</li>
<li>Add the ESP32 to the Tester PCB as a stuff option, so the Test System can be built with only one PCB (without the Tester Controller board). Leave the 20-pin header on the Tester PCB schematic so the old configuration is still possible by installing the 20-pin header and not installing the ESP32.</li>
<li>The UUT power switch is nice but mechanically weak. Figure out another option.</li>
<li>IC6 is not needed. Remove it.</li>
<li>IC3 pin 23 GPIO signal is connected directly to VPP. A software bug can cause an output driven low to be shorted to VPP. Instead, connect IC3 pin 23 through a small-value resistor to VPP.</li>
<li>IC2 pin 1 GPIO signal is connected directly to GND. A software bug can cause an output driven high to be shorted to GND. Instead, connect IC2 pin 1 through a small-value resistor to GND.</li>
<li>Mounting holes, 6 places, need updated pads for soldermask clearance underneath screw heads.</li>
</ol>

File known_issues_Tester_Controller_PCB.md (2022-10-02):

<b>known issues Flip Controller PCB</b>
<p>
<ol>
<li>microSD Adapter clearance - the microSD adapter is located too close to the ESP32. The microSD adapter touches the end of the ESP32.
The microSD location has been moved on the v2 PCB design but v2 has not yet been published.
</ol>

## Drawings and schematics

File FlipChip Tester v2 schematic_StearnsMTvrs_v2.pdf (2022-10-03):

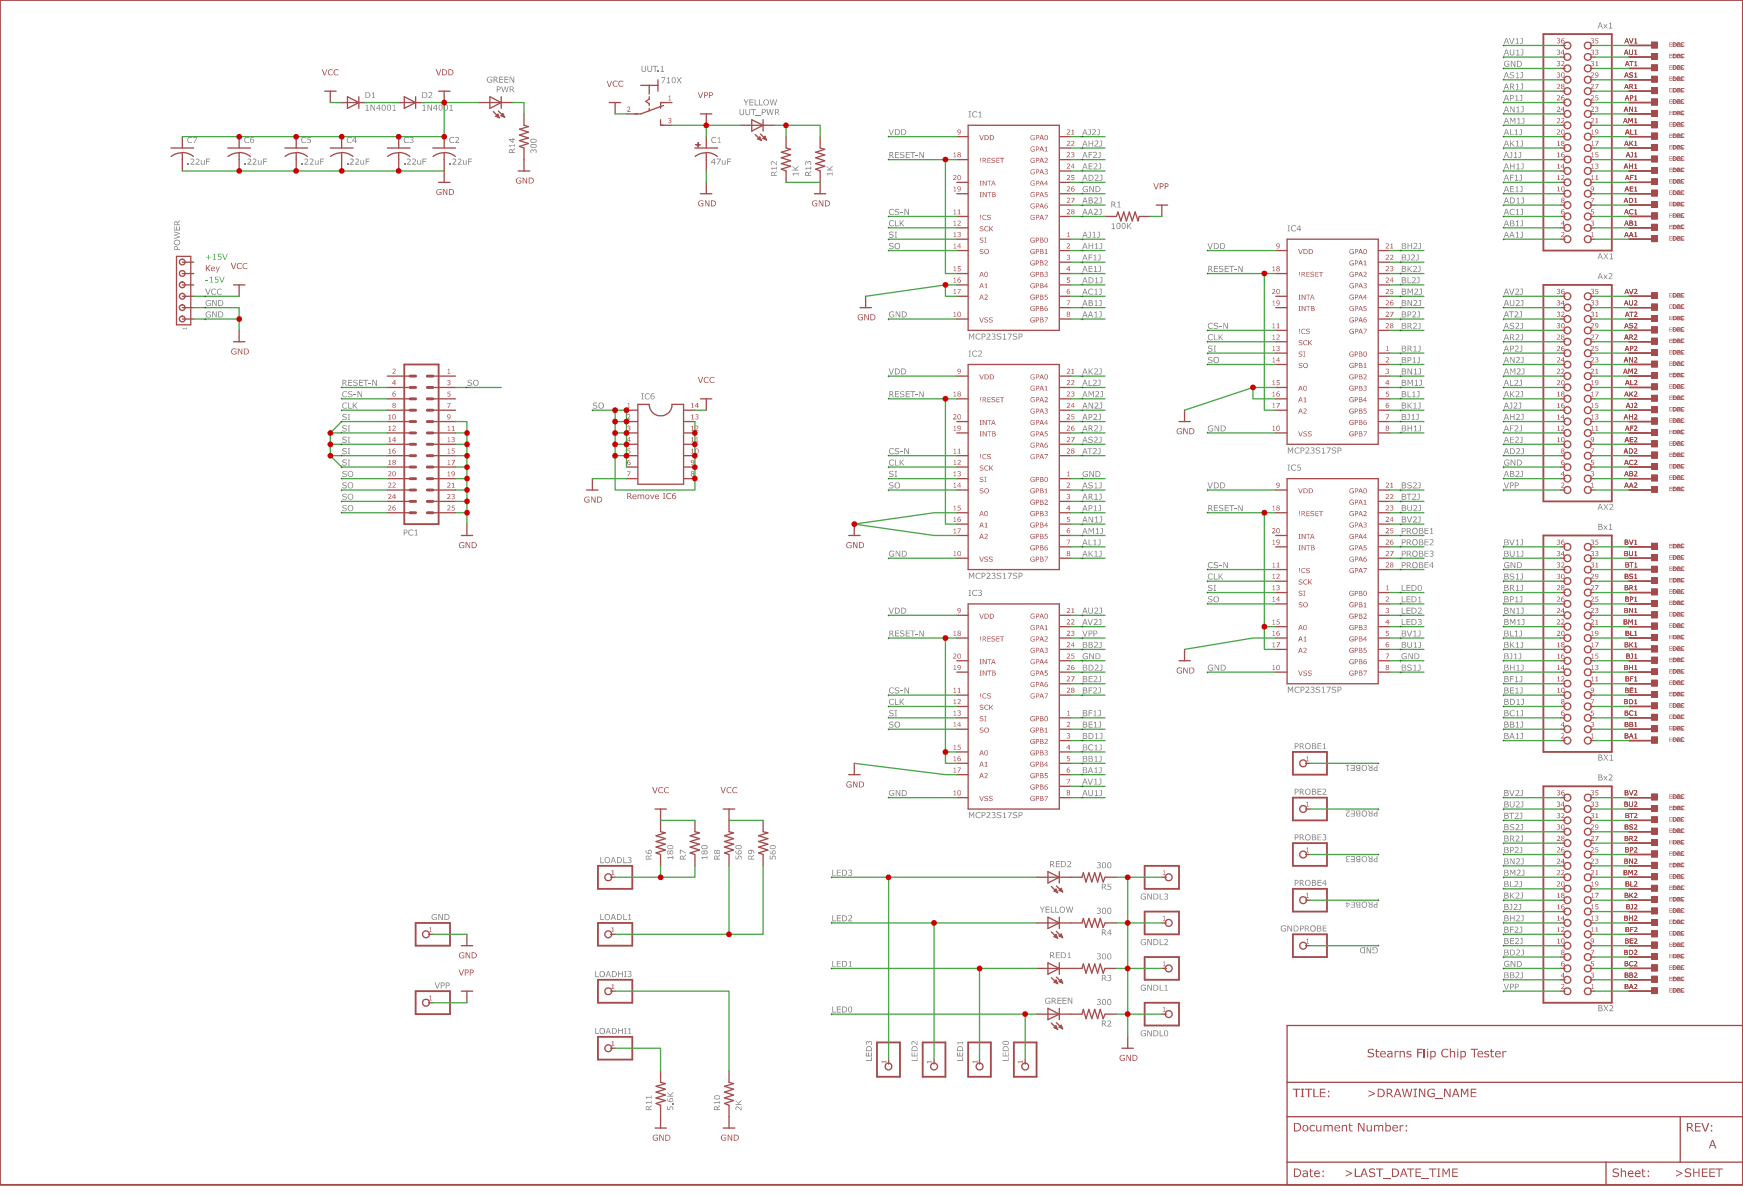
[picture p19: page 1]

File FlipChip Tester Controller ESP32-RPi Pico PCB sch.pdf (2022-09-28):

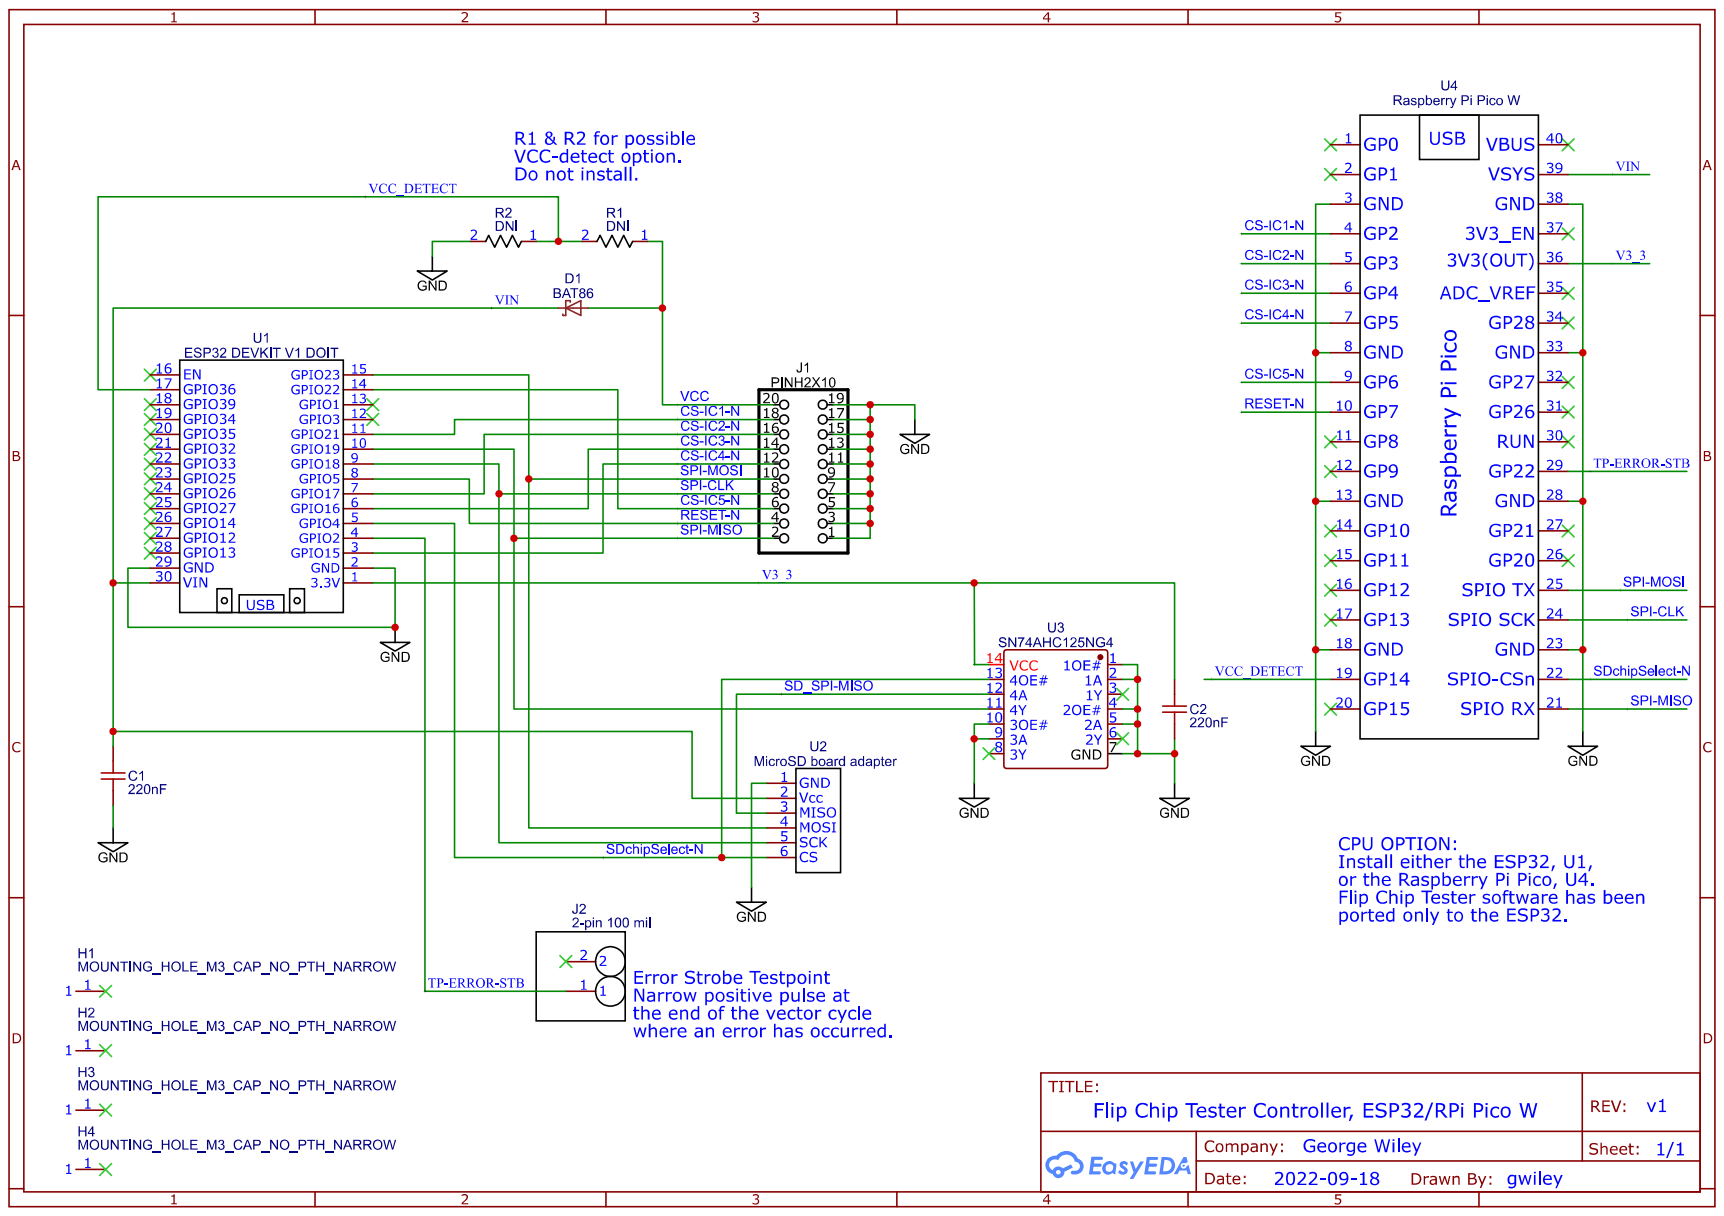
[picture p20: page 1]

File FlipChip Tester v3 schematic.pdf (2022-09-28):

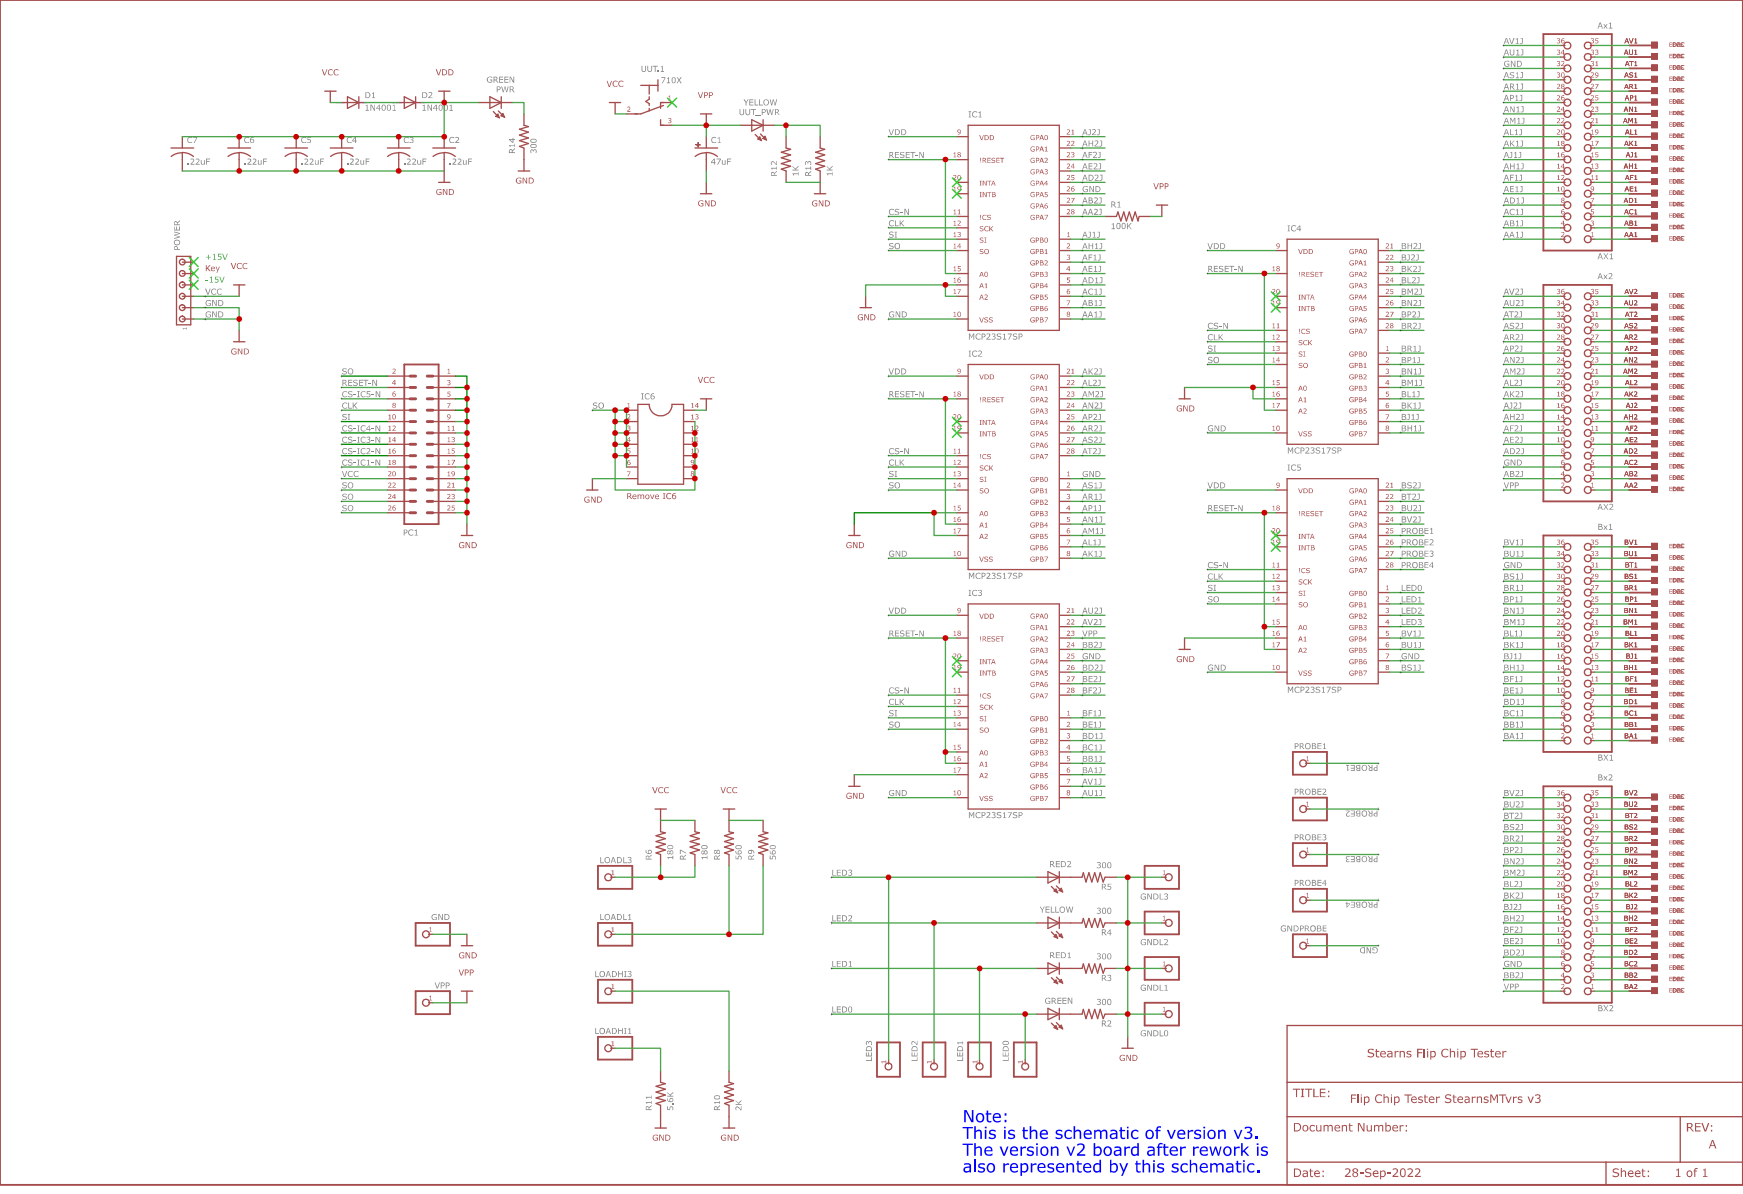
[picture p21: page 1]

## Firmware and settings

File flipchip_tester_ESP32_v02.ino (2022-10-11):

// Flip Chip Tester, port of Stearns Tester code to ESP32 on Arduino
//

//#include <iostream>

/************************************************************************/
/*                                                                      */
/*      tester.c        PDP-8 card tester via SPI                       */
/*                                                                      */
/*                                                                      */
/*      compile with Microsoft C 1.52 with command line:                */
/*              cl /W4 /AL tester.c                                     */
/*                                                                      */
/************************************************************************/

#include "FS.h"
#include "SD.h"
#include "SPI.h"

//#define VERSION_STRING  "version 0.91 November 27, 2015"
#define VERSION_STRING  "version v02 October 11, 2022"

//#define _CRT_SECURE_NO_WARNINGS  1 /* disable Microsoft 'old library' warnings */

// define MCP chip addresses
#define IC1 1
#define IC2 2
#define IC3 3
#define IC4 4
#define IC5 5
#define IODIR_AB 0
#define GPPUA_AB 0x0c
#define GPIO_AB  0x12

const int onboard_ledPin = 2;
const int SDchipSelectPin = 4;
const int MCPchipSelectIC1 = 21;
const int MCPchipSelectIC2 = 17;
const int MCPchipSelectIC3 = 16;
const int MCPchipSelectIC4 = 15;
const int MCPchipSelectIC5 = 22;
const int MCPnresetPin = 5;

//#define SERIAL_TIMEOUT 600000

#define LOG_FILENAME "tester.log"
char  print_buffer[1024];
//char  print_buffer[512];
File file_test;

// modification to the original print function
// outputs a char array called "buffer" to the console and to the Log File
//
void print(const char* pbuffer)
{
  Serial.print(String(pbuffer));
  //appendFile(SD, LOG_FILENAME, buffer);
}

// function to print a char buffer
//void print(const char* buffer)
//{
//  printST(string(buffer));
//}

String millis2time() {
  String Time = "";
  unsigned long ss;
  byte mm, hh, dd;
  ss = millis() / 1000;
  dd = ss / 86400;
  hh = (ss - dd * 86400) / 3600;
  mm = (ss - dd * 86400 - hh * 3600) / 60;
  ss = (ss - dd * 86400 - hh * 3600) - mm * 60;
  Time += (String)dd + ":";
  if (hh < 10)Time += "0";
  Time += (String)hh + ":";
  if (mm < 10)Time += "0";
  Time += (String)mm + ":";
  if (ss < 10)Time += "0";
  Time += (String)ss;
  return Time;
}

void str_to_upr(char * cbuffer)
{
  while(*cbuffer != '\0'){
    if((*cbuffer >= 'a') && (*cbuffer <= 'z')) *cbuffer = *cbuffer & 0xdf;
    cbuffer++;
  }
}

void sd_fgets(char * sdfgbuffer, int sd_buffer_size/*, file_test*/)
{
  int sdcharcount = 1;
  char *sdbufferpointer;

  //Serial.println("sd_fgets called");
  sdbufferpointer = sdfgbuffer;
  while(file_test.available()){
    *sdbufferpointer = file_test.read();
    if(*sdbufferpointer == '\n') break;
    //if(*sdbufferpointer == '\r') break;
    if(*sdbufferpointer == '\0') break;
    if(++sdcharcount >= sd_buffer_size) break;
    if(*sdbufferpointer != '\r')
      ++sdbufferpointer;
  }
  *sdbufferpointer = '\0';
  //Serial.println("sd_fgets exit [" + String(sdcharcount) + "]: " + String(sdfgbuffer));
}

void print_timestamp(void)
{
  #define TIME_BUFFER_LENGTH 26
  //uint32_t   now_time32;         /* MSVC 1.52 is only 32 bit times.  BLOWS UP in 2038  */
  char  time_buffer[TIME_BUFFER_LENGTH];
  char* ptr;

  //time(&now_time32);
  String time_since_boot = millis2time();
  //strcpy(time_buffer, ctime(&now_time32));  /* ctime() returns pointer to static 26 character string  */
  // copy the time_since_boot String to the time_buffer char array
  time_since_boot.toCharArray(time_buffer, TIME_BUFFER_LENGTH);
  
  ptr = strchr(time_buffer, '\n'); // these two lines are from the original code, probably no longer needed
  if (ptr != (char*)NULL) *ptr = '\0';

  print(time_buffer);
} 

// Function to write to the MCP23S17
// parameters are chip address, register address, register data
//
void mcpwrite(uint16_t chipaddr, uint16_t regaddr, uint16_t regdata) {
  //MCP23S17 write to IC chipaddr, register pair regaddr, with regdata
  switch(chipaddr){               // assert the chip select signal of the specified MCP chip
    case IC1:
      digitalWrite(MCPchipSelectIC1, LOW);
      break;
    case IC2:
      digitalWrite(MCPchipSelectIC2, LOW);
      break;
    case IC3:
      digitalWrite(MCPchipSelectIC3, LOW);
      break;
    case IC4:
      digitalWrite(MCPchipSelectIC4, LOW);
      break;
    case IC5:
      digitalWrite(MCPchipSelectIC5, LOW);
      break;
    default:
      print("broken sofware, invalid MCP chip address");
  }
  SPI.transfer16(0x4000 | (chipaddr << 9) | regaddr); //Device Opcode, Chip Address, Write, Reg Addr
  //SPI.transfer16(0x4000 | regaddr); //Device Opcode, Write, Reg Addr
  SPI.transfer16(regdata); // Register Data
  digitalWrite(MCPchipSelectIC1, HIGH);
  digitalWrite(MCPchipSelectIC2, HIGH);
  digitalWrite(MCPchipSelectIC3, HIGH);
  digitalWrite(MCPchipSelectIC4, HIGH);
  digitalWrite(MCPchipSelectIC5, HIGH);
}

// Function to read from the MCP23S17
// parameters are chip address, register address
// returns 16-bit value read from the specified chip and register
//
uint16_t mcpread(uint16_t chipaddr, uint16_t regaddr) {
  //MCP23S17 read from IC chipaddr, register pair regaddr, with regdata
  uint16_t mcp_read_data;
  
  switch(chipaddr){               // assert the chip select signal of the specified MCP chip
    case IC1:
      digitalWrite(MCPchipSelectIC1, LOW);
      break;
    case IC2:
      digitalWrite(MCPchipSelectIC2, LOW);
      break;
    case IC3:
      digitalWrite(MCPchipSelectIC3, LOW);
      break;
    case IC4:
      digitalWrite(MCPchipSelectIC4, LOW);
      break;
    case IC5:
      digitalWrite(MCPchipSelectIC5, LOW);
      break;
    default:
      print("broken sofware, invalid MCP chip address");
  }
  SPI.transfer16(0x4100 | (chipaddr << 9) | regaddr); //Device Opcode, Chip Address, Read, Reg Addr
  //SPI.transfer16(0x4100 | regaddr); //Device Opcode, Read, Reg Addr
  mcp_read_data = SPI.transfer16(0x0000); //sending dummy data to read the port
  digitalWrite(MCPchipSelectIC1, HIGH);
  digitalWrite(MCPchipSelectIC2, HIGH);
  digitalWrite(MCPchipSelectIC3, HIGH);
  digitalWrite(MCPchipSelectIC4, HIGH);
  digitalWrite(MCPchipSelectIC5, HIGH);
  return(mcp_read_data);
}


//unsigned short  lpt_base = 0x378;   /* LPT1 on Dell D610    */
/*
unsigned char   lpt_value_last_data_out;
unsigned char   lpt_value_last_control_out;
unsigned char   lpt_value_new_data;
unsigned char   lpt_value_new_control;
unsigned char   lpt_value_status_last_read;
unsigned char   lpt_value_data_last_read;
unsigned char   lpt_value_control_last_read;

void lpt_input_data(void)
{
    //lpt_value_data_last_read = (unsigned char)_inp(lpt_base + 0);
}

void lpt_input_status(void)
{
    //lpt_value_status_last_read = (unsigned char)_inp(lpt_base + 1);
}

void lpt_input_control(void)
{
    //lpt_value_control_last_read = (unsigned char)_inp(lpt_base + 2);
}

void lpt_output_data(void)
{
    lpt_value_last_data_out = lpt_value_new_data;
    //_outp(lpt_base + 0, lpt_value_last_data_out);
}

void lpt_output_control(void)
{
    lpt_value_last_control_out = lpt_value_new_control;
    //_outp(lpt_base + 2, lpt_value_last_control_out);
}

void lpt_init(void)
{
    lpt_input_data();
    lpt_input_control();
    lpt_input_status();

    lpt_value_new_data = lpt_value_data_last_read;
    lpt_value_new_control = lpt_value_control_last_read;

    lpt_output_data();
    lpt_output_control();
}
*/


/* routines that stage next output or use last input    */
/*
void lpt_set_data_bit(unsigned int bit_number)
{
    if (bit_number > 7)
    {
        print("ERROR: broken software\r\n");
        exit(1);
    }
    lpt_value_new_data |= (1 << bit_number);
}

void lpt_clr_data_bit(unsigned int bit_number)
{
    if (bit_number > 7)
    {
        print("ERROR: broken software\r\n");
        exit(1);
    }
    lpt_value_new_data &= ~(1 << bit_number);
}

void lpt_set_control_bit(unsigned int bit_number)
{
    if (bit_number > 7)
    {
        print("ERROR: broken software\r\n");
        exit(1);
    }
    lpt_value_new_control |= (1 << bit_number);
}

void lpt_clr_control_bit(unsigned int bit_number)
{
    if (bit_number > 7)
    {
        print("ERROR: broken software\r\n");
        exit(1);
    }
    lpt_value_new_control &= ~(1 << bit_number);
}

void lpt_toggle_data_bit(unsigned int bit_number)
{
    if (bit_number > 7)
    {
        print("ERROR: broken software\r\n");
        exit(1);
    }
    lpt_value_new_data ^= (1 << bit_number);
}

void lpt_toggle_control_bit(unsigned int bit_number)
{
    if (bit_number > 7)
    {
        print("ERROR: broken software\r\n");
        exit(1);
    }
    lpt_value_new_control ^= (1 << bit_number);
}
*/

//#define SPI_SPARE_PIN_1_LO      (lpt_set_control_bit( 0 ))                          /* pin  1 C0- -Strobe   */
//#define SPI_SPARE_PIN_1_HI      (lpt_clr_control_bit( 0 ))                          /* pin  1 C0- -Strobe   */
//#define SPI_RESET_N_PIN_2_LO    (lpt_clr_data_bit( 0 ))                             /* pin  2 D0+ +Data0    */
//#define SPI_RESET_N_PIN_2_HI    (lpt_set_data_bit( 0 ))                             /* pin  2 D0+ +Data0    */
//#define SPI_CS_N_PIN_3_LO       (lpt_clr_data_bit( 1 ))                             /* pin  3 D1+ +Data1    */
//#define SPI_CS_N_PIN_3_HI       (lpt_set_data_bit( 1 ))                             /* pin  3 D1+ +Data1    */
//#define SPI_CLK_PIN_4_LO        (lpt_clr_data_bit( 2 ))                             /* pin  4 D2+ +Data2    */
//#define SPI_CLK_PIN_4_HI        (lpt_set_data_bit( 2 ))                             /* pin  4 D2+ +Data2    */
//#define SPI_SO_A_PIN_5_LO       (lpt_clr_data_bit( 3 ))                             /* pin  5 D3+ +Data3    */
//#define SPI_SO_A_PIN_5_HI       (lpt_set_data_bit( 3 ))                             /* pin  5 D3+ +Data3    */
//#define SPI_SO_B_PIN_6_LO       (lpt_clr_data_bit( 4 ))                             /* pin  6 D4+ +Data4    */
//#define SPI_SO_B_PIN_6_HI       (lpt_set_data_bit( 4 ))                             /* pin  6 D4+ +Data4    */
//#define SPI_SO_C_PIN_7_LO       (lpt_clr_data_bit( 5 ))                             /* pin  7 D5+ +Data5    */
//#define SPI_SO_C_PIN_7_HI       (lpt_set_data_bit( 5 ))                             /* pin  7 D5+ +Data5    */
//#define SPI_SO_D_PIN_8_LO       (lpt_clr_data_bit( 6 ))                             /* pin  8 D6+ +Data6    */
//#define SPI_SO_D_PIN_8_HI       (lpt_set_data_bit( 6 ))                             /* pin  8 D6+ +Data6    */
//#define SPI_SO_E_PIN_9_LO       (lpt_clr_data_bit( 7 ))                             /* pin  9 D7+ +Data7    */
//#define SPI_SO_E_PIN_9_HI       (lpt_set_data_bit( 7 ))                             /* pin  9 D7+ +Data7    */
//#define SPI_SI_D_PIN_10_IN      ((lpt_value_status_last_read & (1 << 6)) ? 1 : 0)   /* pin 10 S6+ -Ack      */
//#define SPI_SI_E_PIN_11_IN      ((lpt_value_status_last_read & (1 << 7)) ? 0 : 1)   /* pin 11 S7- +Busy     */
//#define SPI_SI_C_PIN_12_IN      ((lpt_value_status_last_read & (1 << 5)) ? 1 : 0)   /* pin 12 S5+ +PaperEnd */
//#define SPI_SI_B_PIN_13_IN      ((lpt_value_status_last_read & (1 << 4)) ? 1 : 0)   /* pin 13 S4+ +SelectIn */
//#define SPI_SPARE_PIN_14_LO     (lpt_set_control_bit( 1 ))                          /* pin 14 C1- -AutoFd   */
//#define SPI_SPARE_PIN_14_HI     (lpt_clr_control_bit( 1 ))                          /* pin 14 C1- -AutoFd   */
//#define SPI_SI_A_PIN_15_IN      ((lpt_value_status_last_read & (1 << 3)) ? 1 : 0)   /* pin 15 S3+ -Error    */
//#define SPI_SPARE_PIN_16_LO     (lpt_clr_control_bit( 2 ))                          /* pin 16 C2+ -Init     */
//#define SPI_SPARE_PIN_16_HI     (lpt_set_control_bit( 2 ))                          /* pin 16 C2+ -Init     */
//#define SPI_SPARE_PIN_17_LO     (lpt_set_control_bit( 3 ))                          /* pin 17 C3- -Select   */
//#define SPI_SPARE_PIN_17_HI     (lpt_clr_control_bit( 3 ))                          /* pin 17 C3- -Select   */
/* pins 18 thru 25 are ground   */


//void spi_output(void)
//{
//    lpt_output_data();
//}


//void spi_input(void)
//{
//    lpt_input_status();
//}


//void spi_init(void)
//{
//    lpt_init();
//
//    SPI_SPARE_PIN_1_LO;     /* spare lo             */
//    SPI_RESET_N_PIN_2_HI;   /* reset-n hi           */
//    SPI_CS_N_PIN_3_HI;      /* remove chip select   */
//    SPI_CLK_PIN_4_HI;       /* clock hi             */
//    SPI_SO_A_PIN_5_LO;      /* data out lo          */
//    SPI_SO_B_PIN_6_LO;      /* data out lo          */
//    SPI_SO_C_PIN_7_LO;      /* data out lo          */
//    SPI_SO_D_PIN_8_LO;      /* data out lo          */
//    SPI_SO_E_PIN_9_LO;      /* data out lo          */
//    SPI_SI_D_PIN_10_IN;     /* input                */
//    SPI_SI_E_PIN_11_IN;     /* input                */
//    SPI_SI_C_PIN_12_IN;     /* input                */
//    SPI_SI_B_PIN_13_IN;     /* input                */
//    SPI_SPARE_PIN_14_LO;    /* spare lo             */
//    SPI_SI_A_PIN_15_IN;     /* input                */
//    SPI_SPARE_PIN_16_LO;    /* spare lo             */
//    SPI_SPARE_PIN_17_LO;    /* spare lo             */
//    spi_output();
//}
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
void loop() {
  int             key;
  //int           exit_flag;
  unsigned int    uTemp;
  static unsigned int    test_delay = 0UL;   // must be static to hold the value
  static unsigned int    test_trigger = 1UL; // must be static to hold the value

  int       i;
  static char      lbuffer[MAX_STRING];
  static char      buffer2[MAX_STRING];
  char* ptr;
  //File file_test;
  char incomingbyte;
  String theinputstring;

  //Serial.println("  *1 test_delay = " + String(test_delay));
  print("\r\n");
  print("\r\n");
  print("Main menu   ");  print_timestamp();  print("\r\n");
  sprintf(print_buffer, "   test file is: %s\r\n", test.filename);
  print(print_buffer);
  sprintf(print_buffer, "   delay is:   %u\r\n", test_delay);
  print(print_buffer);
  //Serial.println("  *2 test_delay = " + String(test_delay));
  sprintf(print_buffer, "   trigger is: %u\r\n", test_trigger);
  print(print_buffer);
  // ESP.getFreeHeap(), ESP.getMinFreeHeap(), ESP.getHeapSize(), ESP.getMaxAllocHeap()
  // https://forum.arduino.cc/t/where-goes-the-esp32-memory/649117
  Serial.println("     free heap:      " + String(ESP.getFreeHeap()));
  Serial.println("     min free heap:  " + String(ESP.getMinFreeHeap()));
  Serial.println("     heap size:      " + String(ESP.getHeapSize()));
  Serial.println("     max alloc heap: " + String(ESP.getMaxAllocHeap()));
  print(" 1 read test file\r\n");
  print(" 2 set test delay\r\n");
  print(" 3 set test trigger\r\n");
  print(" 4 run test\r\n");
  print(" 5 output loading test\r\n");
  print(" 8 diags\r\n");
  print(" 9 exit\r\n");

  key = get_a_key();
  switch (key)
  {
  case '1':   /* read test file    */
    for (;;)      /* will break on success  */
    {
      print("Enter test file name? ");
      //(void)fgets(lbuffer, sizeof(lbuffer), stdin);
      theinputstring = String("");
      while(true){
        if(Serial.available()>0){
          incomingbyte = Serial.read();
          if((incomingbyte != 0x7f) || (theinputstring.length() > 0))
            Serial.print(incomingbyte);
          if((incomingbyte == '\n') || (incomingbyte == '\r')) break;
          if(incomingbyte == 0x7f){
            if(theinputstring.length() > 0)
              theinputstring.remove(theinputstring.length()-1);
          }
          else theinputstring = theinputstring + incomingbyte;
        }
      }
      Serial.println("\nentered: " + String(theinputstring));
      Serial.println("length=" + String(theinputstring.length()));
      theinputstring.toCharArray(lbuffer, sizeof(lbuffer));  // copy the input string to "lbuffer" in legacy code
      
      //ptr = strchr(lbuffer, '\n');
      //if (ptr != (char*)NULL) *ptr = '\0';
      //ptr = strchr(lbuffer, '\r');
      //if (ptr != (char*)NULL) *ptr = '\0';

      //strcpy(buffer2, "tests\\");     /* directory of the tests */
      strcpy(buffer2, "/");              // tests are at the root level on the microSD card
      // for some reason the microSD filesystem wants the leading slash, temporary fix for now -gw
      if ((strlen(buffer2) + strlen(lbuffer) + 2) < sizeof(buffer2)) break;    /* break on success */

      print("test file name is too long. Try again.\r\n");
    }
    strcat(buffer2, lbuffer);    /* lengths have been checked  */
    str_to_upr(buffer2); // convert to uppercase, some issue with microSD filesystem being case sensitive -gw

    Serial.println("main menu, corrected filename: " + String(buffer2));
    sprintf(print_buffer, "trying to open test file: %s\r\n", buffer2);
    print(print_buffer);
    file_test = SD.open(buffer2 /*, "rt"*/);
    if (!file_test /*== (File*)NULL*/)
    {
      print("could not open test file.\r\n");
      print("valid test files are:\r\n");
      //system("dir /a-d tests\\*.*");
      //system("dir /a-d /w tests\\*.*");
      listDir(SD, "/", 0);
      sprintf(print_buffer, "reverting back to test file: %s\r\n", test.filename);
      print(print_buffer);
    }
    else
    {
      strcpy(test.filename, buffer2);
      sprintf(print_buffer, "reading test file: %s\r\n", test.filename);
      print(print_buffer);
      if (read_test(/*file_test*/)) // file_test is now global to simplify conversion to Arduino SD file system
      {
        print("bad test file\r\n");
      }
    }
    break;

    case '2':   /* set test delay   */
      print("Enter test delay (0 to 100)? ");
      //(void)fgets(lbuffer, sizeof(lbuffer), stdin);
      theinputstring = String("");
      while(true){
        if(Serial.available()>0){
          incomingbyte = Serial.read();
          Serial.print(incomingbyte);
          if((incomingbyte == '\n') || (incomingbyte == '\r')) break;
          theinputstring = theinputstring + incomingbyte;
        }
      }
      Serial.println("\nentered: " + theinputstring);
      theinputstring.toCharArray(lbuffer, sizeof(lbuffer));  // copy the input string to "lbuffer" in legacy code

      //ptr = strchr(lbuffer, '\n');
      //if (ptr != (char*)NULL) *ptr = '\0';
      //ptr = strchr(lbuffer, '\r');
      //if (ptr != (char*)NULL) *ptr = '\0';

      i = sscanf(lbuffer, "%u", &uTemp);
      if (i != 1)
      {
        sprintf(print_buffer, "could not 'sscanf(...\"%s\"..)\r\n", lbuffer); // gw - changed to %s and added lbuffer because not enough arguments passed
        print(print_buffer);
      }
      else if (uTemp > 100)
      {
        print("test_delay must be 0 to 100)\r\n");
      }
      else
      {

        sprintf(print_buffer, "setting test delay to: %u\r\n", uTemp);
        print(print_buffer);
        test_delay = uTemp;
        //Serial.println("  *test_delay = " + String(test_delay));
      }
      break;

    case '3':   /* set test trigger   */
      if (test.number_steps == 0)
      {
        print("there are no test steps\r\n");
      }
      else
      {
        sprintf(print_buffer, "Enter test trigger (1 to %u)? ", test.number_steps);
        print(print_buffer);
        //(void)fgets(lbuffer, sizeof(lbuffer), stdin);
        theinputstring = String("");
        while(true){
          if(Serial.available()>0){
            incomingbyte = Serial.read();
            Serial.print(incomingbyte);
            if((incomingbyte == '\n') || (incomingbyte == '\r')) break;
            theinputstring = theinputstring + incomingbyte;
          }
        }
        Serial.println("\nentered: " + theinputstring);
        theinputstring.toCharArray(lbuffer, sizeof(lbuffer));  // copy the input string to "lbuffer" in legacy code

        //ptr = strchr(lbuffer, '\n');
        //if (ptr != (char*)NULL) *ptr = '\0';
        //ptr = strchr(lbuffer, '\r');
        //if (ptr != (char*)NULL) *ptr = '\0';

        i = sscanf(lbuffer, "%u", &uTemp);
        if (i != 1)
        {
          sprintf(print_buffer, "could not 'sscanf(...\"%s\"..)\r\n", lbuffer); // gw - changed to %s and added lbuffer because not enough arguments passed
          print(print_buffer);
        }
        else if ((uTemp < 1) || (uTemp > test.number_steps))
        {
          sprintf(print_buffer, "test_trigger must be 1 to %u)\r\n", test.number_steps);
          print(print_buffer);
        }
        else
        {
          sprintf(print_buffer, "setting test delay to: %u\r\n", uTemp);
          print(print_buffer);
          test_trigger = uTemp;
        }
      }
      break;

    case '4':   /* run test             */
    case '5':   /* output loading test  */
      if (strcmp(test.filename, TEST_FILENAME_NONE) == 0)
      {
        print("there is no test file\r\n");
      }
      else if (test.number_columns == 0)
      {
        print("there are no test columns\r\n");
      }
      else if (test.number_steps == 0)
      {
        print("there are no test steps\r\n");
      }
      else if (tester_init_and_uut_power_verify())
      {
        /* error already printed    */
      }
      else
      {
        if (key == '4')
        {
          run_a_test(test_delay, test_trigger);
        }
        else if (key == '5')
        {
          /* check for outputs    */
          for (uTemp = 0; uTemp < test.number_columns; uTemp++)
          {
            if (test.columns[uTemp].pdirection == 'O') break;
          }
          if (uTemp >= test.number_columns)
          {
            print("there are no outputs\r\n");
          }
          else
          {
            output_load_test();
          }
        }
      }
      break;

    case '8':   /* diags    */
      do_diags();
      break;

    case '9':
    case 'Q':
    case 'q':
    case KEY_ESCAPE:
      print("\r\nExit command entered, no exit on Arduino\r\n"); //added for Arduino version -gw
      //exit_flag = 1;
      break;
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

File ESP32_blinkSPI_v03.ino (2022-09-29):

// Board: "DOIT ESP32 DEVKIT V1"
// Board: "ESP32 Dev Module"
#include <SPI.h>

#define IC1 1
#define IC2 2
#define IC3 3
#define IC4 4
#define IC5 5
#define IODIR_AB 0
#define GPPUA_AB 0x0c
#define GPIO_AB  0x12
#define REG_IOCON   0x0A        /* I/O config           */

const int onboard_ledPin = 2;
const int SDchipSelectPin = 4;
const int MCPchipSelectIC1 = 21;
const int MCPchipSelectIC2 = 17;
const int MCPchipSelectIC3 = 16;
const int MCPchipSelectIC4 = 15;
const int MCPchipSelectIC5 = 22;
const int MCPnresetPin = 5;
int icount, portread;

// Function to write to the MCP23S17
// parameters are chip address, register address, register data
//
void mcpwrite(uint16_t chipaddr, uint16_t regaddr, uint16_t regdata) {
  //MCP23S17 write to IC chipaddr, register pair regaddr, with regdata
  switch(chipaddr){               // assert the chip select signal of the specified MCP chip
    case IC1:
      digitalWrite(MCPchipSelectIC1, LOW);
      break;
    case IC2:
      digitalWrite(MCPchipSelectIC2, LOW);
      break;
    case IC3:
      digitalWrite(MCPchipSelectIC3, LOW);
      break;
    case IC4:
      digitalWrite(MCPchipSelectIC4, LOW);
      break;
    case IC5:
      digitalWrite(MCPchipSelectIC5, LOW);
      break;
    default:
      Serial.println("broken sofware, invalid MCP chip address");
  }
  SPI.transfer16(0x4000 | (chipaddr << 9) | regaddr); //Device Opcode, Chip Address, Write, Reg Addr
  SPI.transfer16(regdata); // Register Data
  digitalWrite(MCPchipSelectIC1, HIGH);
  digitalWrite(MCPchipSelectIC2, HIGH);
  digitalWrite(MCPchipSelectIC3, HIGH);
  digitalWrite(MCPchipSelectIC4, HIGH);
  digitalWrite(MCPchipSelectIC5, HIGH);
}

// Function to read from the MCP23S17
// parameters are chip address, register address
// returns 16-bit value read from the specified chip and register
//
uint16_t mcpread(uint16_t chipaddr, uint16_t regaddr) {
  //MCP23S17 read from IC chipaddr, register pair regaddr, with regdata
  uint16_t mcp_read_data;
  
  switch(chipaddr){               // assert the chip select signal of the specified MCP chip
    case IC1:
      digitalWrite(MCPchipSelectIC1, LOW);
      break;
    case IC2:
      digitalWrite(MCPchipSelectIC2, LOW);
      break;
    case IC3:
      digitalWrite(MCPchipSelectIC3, LOW);
      break;
    case IC4:
      digitalWrite(MCPchipSelectIC4, LOW);
      break;
    case IC5:
      digitalWrite(MCPchipSelectIC5, LOW);
      break;
    default:
      Serial.println("broken sofware, invalid MCP chip address");
  }
  SPI.transfer16(0x4100 | (chipaddr << 9) | regaddr); //Device Opcode, Chip Address, Read, Reg Addr
  mcp_read_data = SPI.transfer16(0x0000); //sending dummy data to read the port
  digitalWrite(MCPchipSelectIC1, HIGH);
  digitalWrite(MCPchipSelectIC2, HIGH);
  digitalWrite(MCPchipSelectIC3, HIGH);
  digitalWrite(MCPchipSelectIC4, HIGH);
  digitalWrite(MCPchipSelectIC5, HIGH);
  return(mcp_read_data);
}

// MCPinitializeIOCON initializes BANK and HAEN so registers are not banked and hardware addr is used
// MCP23S17 8-bit write to IOCON, BANK=0, SEQOP=0, HAEN=0, 0x00, all 5 chips
//
void MCPinitializeIOCON(){
  int tchipaddress;
  for(tchipaddress=1; tchipaddress<=5; tchipaddress++){
    mcpwrite(tchipaddress, REG_IOCON, 0x0000); //IOCON data value: BANK=0, HAEN=0, 0x00; was BANK=0, HAEN=1, 0x08
  }
}

void setup() {
  pinMode(onboard_ledPin, OUTPUT); // initialize the onboard LED pin as an output

  //initialize chip select pins
  pinMode(MCPchipSelectIC1, OUTPUT); // initialize MCP SPI Chip Select pin for IC1
  digitalWrite(MCPchipSelectIC1, HIGH); // initialize MCP Chip Selectpin for IC1 to the inactive (HIGH) state
  pinMode(MCPchipSelectIC2, OUTPUT); // initialize MCP SPI Chip Select pin for IC2
  digitalWrite(MCPchipSelectIC2, HIGH); // initialize MCP Chip Selectpin for IC2 to the inactive (HIGH) state
  pinMode(MCPchipSelectIC3, OUTPUT); // initialize MCP SPI Chip Select pin for IC3
  digitalWrite(MCPchipSelectIC3, HIGH); // initialize MCP Chip Selectpin for IC3 to the inactive (HIGH) state
  pinMode(MCPchipSelectIC4, OUTPUT); // initialize MCP SPI Chip Select pin for IC4
  digitalWrite(MCPchipSelectIC4, HIGH); // initialize MCP Chip Selectpin for IC4 to the inactive (HIGH) state
  pinMode(MCPchipSelectIC5, OUTPUT); // initialize MCP SPI Chip Select pin for IC5
  digitalWrite(MCPchipSelectIC5, HIGH); // initialize MCP Chip Selectpin for IC5 to the inactive (HIGH) state
  pinMode(MCPnresetPin, OUTPUT); // initialize MCP not-reset pin for IC1-IC5
  digitalWrite(MCPnresetPin, HIGH); // initialize MCP not-reset to the inactive (HIGH) state
  pinMode(SDchipSelectPin, OUTPUT); // initialize SD Chip Select pin
  digitalWrite(SDchipSelectPin, HIGH); // initialize SD Chip Select to the inactive (HIGH) state

  Serial.begin(115200);
  icount = 0;
  Serial.println();
  Serial.println("Start blink test");

  delay(100);
  //initialize SPI (VSPI pins)
  SPI.beginTransaction(SPISettings(5000000, MSBFIRST, SPI_MODE0));
  SPI.begin();
  
  //MCP23S17 8-bit write to IOCON, BANK=0, SEQOP=0, HAEN=1, 0x08, all 5 chips at once
  //  all 5 chips are written simultaneously with the following because HAEN=0 after power reset
  MCPinitializeIOCON();
  //delay(10);

  //MCP23S17 write to IC5, IODIRA & IODIRB, with IODIRB bits 0-3 as outputs, 0xf0
  mcpwrite(IC5, IODIR_AB, 0xfff0);

  //MCP23S17 write to IC5, GPPUA & GPPUB, with PROBE1 - PROBE4 having pullups, GPPUA[7:4]
  mcpwrite(IC5, GPPUA_AB, 0xf000);

  //MCP23S17 write to IC1, IODIRA & IODIRB, with all IODIRA & IODIRB bits as outputs, 0x0000
  mcpwrite(IC1, IODIR_AB, 0x0000);
}

void loop() {
  delay(800);
  digitalWrite(onboard_ledPin, HIGH);  // Turn the LED on by setting the voltage HIGH
  mcpwrite(IC5, GPIO_AB, 0x0008); //MCP23S17 write to IC5, GPIOA & GPIOB, 0x08

  portread = mcpread(IC5, GPIO_AB); //MCP23S17 read from IC5, GPIOA & GPIOB
  Serial.println(String("  Read 1st ") + String(portread,BIN));

  delay(500);
  digitalWrite(onboard_ledPin, LOW);  // Turn the LED off by setting the voltage LOW
  mcpwrite(IC5, GPIO_AB, 0x0002); //MCP23S17 write to IC5, GPIOA & GPIOB,0x00

  portread = mcpread(IC5, GPIO_AB); //MCP23S17 read from IC5, GPIOA & GPIOB
  Serial.println(String("  Read 2nd ") + String(portread,BIN));

  delay(500);
  mcpwrite(IC1, GPIO_AB, 0x55aa); //MCP23S17 write to IC1, GPIOA & GPIOB,0x55aa

  delay(500);
  mcpwrite(IC1, GPIO_AB, 0xaa55); //MCP23S17 write to IC1, GPIOA & GPIOB,0xaa55

  Serial.println(String(icount++) + " " + String(portread,BIN));
}

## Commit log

2022-10-03 Add files via upload
    FlipChip Tester v2 schematic_StearnsMTvrs_v2.pdf is a schematic of the FlipChip tester PCB before rework modifications.
2022-10-05 Add files via upload
    * Fixed test filename entry problem with deleting characters using backspace.
    * Removed various print statements that were used for debugging.
    * Updated splash screen.
    * commented out some unnecessary LPT functions.
    [flipchip_tester_ESP32_v01.ino]
